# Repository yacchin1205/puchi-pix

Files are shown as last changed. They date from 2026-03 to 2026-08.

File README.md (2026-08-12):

# Puchi-Pix (ぷちぴく)

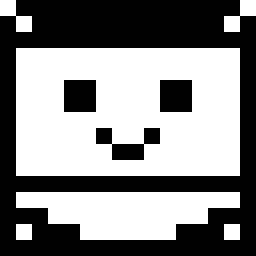
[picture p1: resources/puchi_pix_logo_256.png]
Puchi-Pix logo


A tiny pixel art display kit powered by STM32G030F6P, with a 96x64 OLED (SSD1331) or TFT display.

## Concept

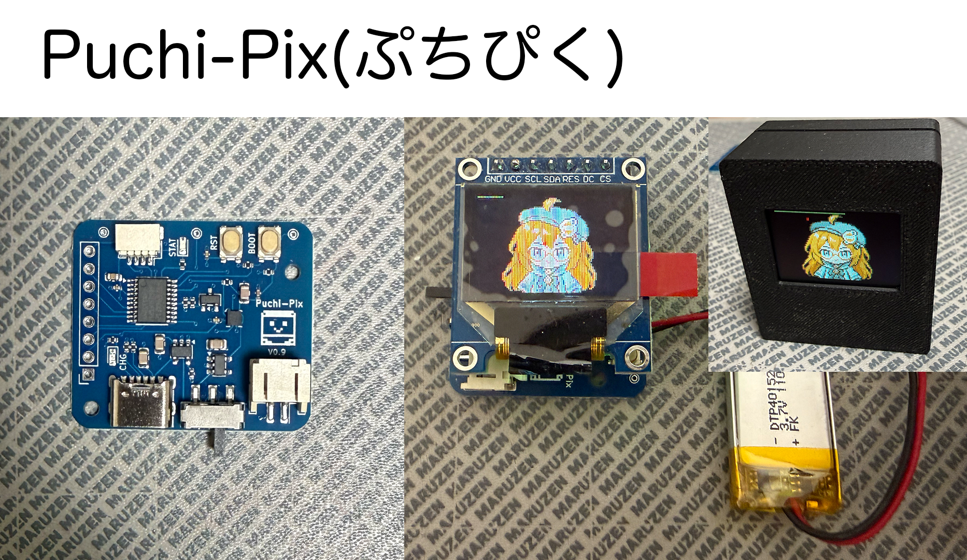
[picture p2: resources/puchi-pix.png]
Puchi-Pix overview


Puchi-Pix was born from a simple desire: to carry pixel art animations in your pocket.

It pairs an STM32G030F6P with a small OLED, targeting a keychain-sized form factor. Rather than a coin cell with its tedious battery swaps, the board integrates a LiPo charger on-board — unusual for something this small, but essential for a device meant to live in your pocket. Exposed GPIO and an onboard accelerometer also make it a capable dev board.

The STM32G030F6P has just 32KB of flash. Fitting animated pixel art into that space demands inter-frame delta compression, 4-bit palettes, and every byte counted. The kind of constraint that once made a project like this feel out of reach for a weekend hack.

Enter the age of coding agents. What used to take careful hand-optimization now becomes a conversation — iterate on compression schemes, generate frame data, and push against hardware limits at the speed of thought. The constraint doesn't go away, but it stops being a barrier and starts being a craft.

Puchi-Pix is a project built for this era — constrained hardware, creative ambition, and an AI coding agent to bridge the gap.

## STM32G030 BOOT0 pin issue

The factory default option bytes have `nBOOT_SEL=1`, which ignores the physical BOOT0 pin. A fresh (empty flash) chip boots into the bootloader automatically, but once firmware is written, the BOOT button has no effect.

Before the first firmware upload, set `nBOOT_SEL=0` via STM32CubeProgrammer CLI:

```bash
STM32_Programmer_CLI -c port=/dev/cu.usbserial-XXXXX br=115200 -ob nBOOT_SEL=0
```

Verify with:

```bash
STM32_Programmer_CLI -c port=/dev/cu.usbserial-XXXXX br=115200 -ob displ
```

`nBOOT_SEL : 0x0 (BOOT0 signal is defined by BOOT0 pin value (legacy mode))` means BOOT+RST will work.

## ESP32 upload fails despite BOOT+RST

On the ESP32 board, entering the bootloader with BOOT+RST sometimes doesn't take — the upload hangs at `Connecting...` for a while and then errors out with:

```
A fatal error occurred: Failed to connect to ESP32-C3: No serial data received.
```

BOOT (GPIO9) is a strapping pin sampled the moment reset is released, so what matters is the button order, not how long anything is held:

1. Press and **hold** BOOT
2. Press and release RST while still holding BOOT
3. Wait a beat, **then** release BOOT — releasing it before (or together with) RST boots the app normally instead
4. Give the USB port a second or two to re-enumerate, then start the upload

If it still fails, power-cycle the board completely and enter the bootloader
before plugging USB back in (on battery power) — this connects reliably:

1. Unplug USB
2. Slide switch OFF, then back ON
3. BOOT+RST (sequence above)
4. Plug USB back in, wait for the port to appear, then start the upload

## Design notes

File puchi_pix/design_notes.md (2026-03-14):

# AI支援によるKiCad PCB設計からJLCPCB発注まで — 体験記

## はじめに

STM32マイコンを使った小型デバイス「iconcard」（約30mm x 30mm x 10mm）のPCB設計を、AI（Claude Code）の支援を受けながら実施し、JLCPCBへのPCBA発注までを完走した。ユニバーサル基板のプロトタイプは動作済みで、KiCadで回路図も描いてあったが、PCB設計とPCBA発注は初めての経験だった。

本稿では、AIにどのような支援を求め、何がうまくいき、何に注意が必要だったかを記録する。

## デバイスの構成

| 部品 | 役割 |
|---|---|
| STM32G030F6Px (TSSOP-20) | MCU |
| SSD1331 OLED (96x64, SPI) | ディスプレイ |
| KXTJ3-1057 (LGA-12) | 加速度センサー |
| MCP73831 (SOT-23-5) | LiPo充電IC |
| AP2112K-3.3 (SOT-23-5) | 3.3V LDOレギュレータ |
| USB-C 6P | 充電用 |
| スライドスイッチ、タクトスイッチ×2 | 電源、BOOT、RST |

## 作業フロー全体像

```
回路図レビュー → 回路修正 → 部品選定 → フットプリント割り当て
→ PCBレイアウト → DRC/ERC → 製造ファイル生成 → JLCPCB発注
```

所要時間は2セッション（各数時間）。以下、各フェーズでAIに何を頼み、何が起きたかを記す。

---

## Phase 1: 回路図レビュー

### AIにできたこと

KiCadの回路図ファイル（`.kicad_sch`）はS式のテキストフォーマットなので、AIが直接読める。AIに回路図のレビューを依頼したところ、配線の座標を追跡して全接続を検証し、以下の問題を発見した。

- **MCP73831のVDD/STATピンが入れ替わっていた**（致命的）
- **LiPo電圧(4.2V)がSTM32の絶対最大定格(4.0V)を超える**（LDOの追加が必要）
- **電源スイッチがモメンタリだった**（スライドスイッチへの変更が必要）
- 未使用ピンのno_connectマーカー不足

### 実際のやりとり

> **自分:** 最初にユニバーサル基板で試作して、PCBを作ろうと回路図に起こしてみたんです。何か、回路図に抜けなどないか、レビューいただけますか
>
> **AI:** 回路図の全ワイヤ接続をトレースしました。コードのピンアサインと照合してレビューします。
>
> **1. MCP73831 の VDD と STAT が逆に配線されている可能性が高い**
>
> 現在の配線をトレースすると：
> - VDD (pin 4) → R8 (2K) → CHARGE_STATUS LED → VBUS
> - STAT (pin 1) → 未接続
>
> VDDはUSB電源入力ピンなのでVBUSに直結が必要です。現状ではR8+LEDで大きな電圧降下が発生し、充電ICが動作しません。
>
> **2. LiPo電圧がSTM32の定格を超える**
>
> VBAT（MCP73831出力 = 4.20V）がSW1を通じてSTM32 VDDに直結されています。STM32G030F6のVDD絶対最大定格は4.0V。満充電時の4.2Vで定格超過になります。

AIはKiCadの .kicad_sch ファイル（S式テキスト）を直接パースし、ワイヤ座標を追跡してピン接続を再構成する。ソースコード(.ino)のピンアサインとも照合した上で、配線ミスと定格超過を検出した。

### 教訓

AIは回路図のテキストデータを直接パースして接続を追えるので、セカンドオピニオンとして有効。ただし、回路図の「意図」は人間が持っているので、AIの指摘に対して自分で判断する必要はある。

---

## Phase 2: 回路修正

修正自体はKiCadの回路図エディタで自分で行い、保存後にAIに再確認を依頼するサイクルを回した。

- AP2112K-3.3 LDO追加（AIが推奨、データシートの接続を確認）
- スライドスイッチへの変更（DPDT → SPDTへ簡素化）
- ENピンのVIN接続、no_connectマーカー追加

### 実際のやりとり

> **自分:** 1.は回路図起こしの際のミスだったので、直しました。3.3V LDOレギュレータを追加（推奨） ってのは、どうやるのがおすすめ？
>
> **AI:** おすすめ: AP2112K-3.3。SOT-23-5で、MCP73831と同じパッケージです。低ドロップアウト（250mV @ 300mA）-- LiPoが3.5Vまで下がっても3.3V出力可能。低静止電流（55uA）-- スリープ時のバッテリー消費が小さい。

> **自分:** ありがとう。修正してみました。確認ください
>
> **AI:** EN → VIN 接続: OK。ワイヤを追跡した結果:
> ```
> U4 EN (132.08, 54.61) → (130.81, 54.61) → (130.81, 52.07) [junction] → U4 VIN
> ```
> ENピンがVINラインにジャンクション経由で正しく接続されています。
>
> スイッチ Pin 3 (C) の no_connect: 未追加。上側ポールのPin 3にはまだno_connectマーカーが付いていません。

KiCadの回路図は座標ベースのテキストデータなので、AIが修正前後の差分を読み取れる。「修正しました」→「確認ください」のサイクルを何度も回せるのが、この協業スタイルの利点。

---

## Phase 3: JLCPCB部品選定

### AIにできたこと

- JLCPCBの部品ページ（URL）を渡すと、スペック・在庫・価格を読み取って要件との適合を判断
- 部品種別ごとの選定ポイント（USB-Cのピン数、コネクタの極性、パッケージサイズ等）を助言
- Basic/Extended部品の違いとコストへの影響を説明
- EOL部品（廃番）の代替品探し

### 実際のやりとり

> **自分:** USB-Cコネクタ選定のポイントはなんだろうか
>
> **AI:** 回路図ではUSB-Cから使っているのは VBUS、GND、CC1/CC2（5.1Kプルダウン）だけ。D+/D-は使っていない。つまり電源供給専用なので、最小限のピンがあれば足ります。

> **自分:** https://jlcpcb.com/partdetail/CK-KMR221GLFS/C72443 こんなんでどうだろうか
>
> **AI:** C&K製で品質は良いですが、1個$0.51〜$0.62とかなり高いです。RST + BOOTで2個必要なので$1以上になります。RST/BOOTは開発時にしか使わないスイッチなので、安いもので十分とも言えます。どうしますか？

JLCPCBの部品ページのURLを貼ると、AIがページを取得してスペック・在庫・価格を読み取り、回路の要件との適合を判断してくれる。自分で部品を探し、AIに「これどう？」と聞くスタイルが効率的だった。

### 注意が必要だったこと

**JLCPCB部品の在庫は流動的。** 選定時に在庫があっても、発注時には0になっていることが複数回あった。タクトスイッチは3回変更することになった：

1. E-Switch TL3301AF160QG (6x6mm) → 在庫切れ
2. HX-3x6x2.5-X (3x6mm) → これも在庫切れ
3. Alps Alpine SKRPACE010 (4.2x3.2mm) → 在庫あり

部品変更のたびにフットプリント再生成が必要になるので、時間のロスが大きい。可能なら、在庫が潤沢な部品（数万個以上）を選ぶか、Basic partを優先するのが良い。

---

## Phase 4: フットプリント割り当て

### easyeda2kicad — 重要ツール

JLCPCBの部品にはEasyEDA形式のフットプリントが用意されているが、KiCadでは直接使えない。`easyeda2kicad` というPythonツールで変換できる：

```bash
pip install easyeda2kicad
easyeda2kicad --full --lcsc_id C139797 --output ./custom_footprints/SKRPACE010
```

LCSC番号を指定するだけで、シンボル・フットプリント・3Dモデルが生成される。EasyEDAのアカウント登録は不要。

### パッド名の不一致問題

生成されたフットプリントのパッド名が、KiCadの回路図シンボルのピン名と一致しないことがある。これは手動で修正が必要：

- **タクトスイッチ（4パッド → 2ピン）:** 内部で繋がっているパッド同士を同じピン番号にリネーム。**必ずデータシートで内部接続を確認すること。**
- **USB-C:** シールドパッド「7」→「S1」にリネーム

### 実際のやりとり

> **自分:** EasyEDAという画面が開いたが... ダウンロードできるのだろうか。Registerする必要がある？
>
> **AI:** もっと簡単な方法があります。easyeda2kicad コマンドラインツール -- アカウント不要で、JLCPCB部品番号からKiCadフットプリントを直接生成できます。
> ```
> pip install easyeda2kicad
> easyeda2kicad --lcsc_id C49023767 --output ./custom_footprints/MST-12D18G4
> ```

> **自分:** SW, USB-Cをフットプリント割り当てしたが、SWもピン表記が違うよね。きっと。
>
> **AI:** パッド名を確認しました。タクトスイッチ -- KiCadの SW_Push シンボルはピン2つ（1と2）しかありません。フットプリントは4パッドです。左の2パッド → 両方とも "1" に、右の2パッド → 両方とも "2" に。

AIはフットプリントファイル（.kicad_mod）も直接読めるので、パッド名の不一致を検出できる。ただし、どのパッド同士が内部接続されているかはデータシートの確認が必須。実際、自分がデータシートを見ずにリネームしてしまい、やり直すことになった。

---

## Phase 5: PCBレイアウト

PCBレイアウト自体はKiCadのPCBエディタで手動で行った。AIに聞いて役立った知識：

- **GND戦略:** B.Cu（裏面）をGNDベタにして、デカップリングコンデンサのGNDパッドからビアで落とす
- **ビア配置:** GNDパッドの近くに配置するほどインピーダンスが下がる
- **シルクスクリーン:** F.SilkSは基板に印刷される、F.Fabは印刷されない
- **ネジ穴:** `MountingHole` フットプリントを使用、30mm基板ならM2サイズ

### 実際のやりとり

> **自分:** 配線で、GNDはどうするのが良いかな
>
> **AI:** 基本方針は裏面（B.Cu）をGNDベタプレーンにすることです。GNDの配線は引かない -- 各部品のGNDパッドにビアだけ打ちます。

> **自分:** GNDピアと端子の間は狭い方が良い？
>
> **AI:** はい、狭い方が良いです。特に重要なのはデカップリングコンデンサのGNDパッドです。ここの配線が長いと、コンデンサの効果が薄れます。理想はコンデンサのGNDパッドから 0.3〜0.5mm の距離にビアです。

PCBレイアウトのGUI操作はAIにはできないが、「何をどう配置すべきか」「なぜそうすべきか」の知識は正確に提供してくれる。手を動かすのは自分、判断の根拠はAIに聞く、という分担。

---

## Phase 6: DRC/ERC

KiCadのDRC/ERCレポート（`.rpt`ファイル）をAIに読ませると、各エラーの意味と対処法を日本語で解説してくれる。

主な問題と対処：

| エラー | 原因 | 対処 |
|---|---|---|
| annular_width | スイッチ固定穴のパッド径 < ドリル径 | PTH → NPTHに変更 |
| power_pin_not_driven | 電源入力ピンの駆動元がない | PWR_FLAGシンボルを追加 |
| unconnected_items | 配線未完了 | 配線を完了 |
| silk_edge_clearance | シルクが基板端からはみ出し | cosmetic、無視可 |

### 実際のやりとり

> **自分:** 自分で直せそうな奴は直したのだが、20260301 ってreportファイルを保存した
>
> **AI:** *(レポートファイルを読んで)* スライドスイッチ(Power)の固定穴 x2 -- アニュラー幅が-0.004mmになっている。穴に対してパッドが小さすぎます。

> **自分:** 電気的に不要 と思っていいですよね。
>
> **AI:** はい、その通りです。Power スライドスイッチの2つの取り付け穴は機械的な固定専用で、電気的には不要です。PTH → NPTHに変更すれば、annular_widthエラーとpadstack警告の計4件が一度に解消します。

KiCadのDRC/ERCが出力する .rpt ファイル（日本語）をそのままAIに渡すと、各エラーの意味を噛み砕いて説明し、具体的な修正手順を示してくれる。

**回路図↔PCBの整合性チェック** はPCBエディタのF8（回路図から基板を更新）で「変更なし」が出れば一致している。

---

## Phase 7: 製造ファイル生成

### Fabrication Toolkit（KiCadプラグイン）

KiCadのPlugin & Content ManagerからインストールできるFabrication Toolkitが便利。ワンクリックでJLCPCB向けのGerber、BOM、CPLファイルを生成する。

### 落とし穴

1. **LCSCフィールドが空になる:** 回路図でLCSCフィールドを追加した後、PCBエディタでF8して同期しないとBOMに反映されない
2. **DNPとExclude from BOMは別:** 回路図上の×マーク（DNP）だけではBOMから除外されない。「Exclude from BOM」チェックが別途必要
3. **production/backups/ が生成される:** .gitignoreに追加しておくのが良い

### 実際のやりとり

> **自分:** OK, production ディレクトリができた。どうだろうか
>
> **AI:** *(BOM CSVを読んで)* ファイル生成は成功しています。2点修正が必要です。LCSC Part # が全て空です。DISPLAY（J2）が BOM に含まれています。

> **自分:** LCSCの項目に、列チェックが入っていなかったので、入れ直してみました
>
> **AI:** *(再度読んで)* まだ空ですね。おそらく回路図の変更がPCBに反映されていないのが原因です。Fabrication Toolkit はPCBファイルから BOM を生成するので、回路図で追加した LCSC フィールドをPCBに同期する必要があります。PCBエディタで F8 → 適用 → 再度 Generate してください。

AIが生成されたCSVファイルを直接読んでチェックしてくれるので、「生成→確認→修正→再生成」のサイクルを素早く回せた。LCSCフィールドがPCBに同期されないというKiCad特有の落とし穴も、AIの指摘で解決できた。

---

## Phase 8: JLCPCB発注

### 発注の流れ

1. jlcpcb.com で Gerber ZIP をアップロード → PCB仕様を選択
2. PCBAを有効化 → BOM CSV と CPL CSV をアップロード
3. 部品マッチング確認 → コンポーネント配置プレビュー → 発注

### 「Confirm Parts Placement」はYesにすべき

JLCPCBのエンジニアが部品配置をレビューしてくれる。追加費用なし。今回、**これがSTM32のLCSC番号誤りを検出してくれた。**

### LCSC番号の取り違え — 最大の失敗

BOMに記載したU1のLCSC番号 C526973 は、実はSTM32G030F6Pxではなく**10pF 0402コンデンサ**だった。JLCPCBのエンジニアが「パッケージが合わない」と連絡してきて発覚。

**対策:** 発注前に、全LCSC番号をJLCPCBの部品ページで照合すべき。AIに頼んで全件検証したところ、この1件以外は全て正しかった。番号の出典が不確かなものは特に注意。

### 実際のやりとり

> **自分:** *(JLCPCBのエンジニア Doris からのメールを貼り付けて)*
> "seems the packages of the parts (U1) cannot match the corresponding pads on the PCB board, so we are unable to assemble them."
>
> **AI:** 原因がわかりました！ C526973 は STM32G030F6Px ではなく、0402 コンデンサ (10pF) です。LCSC 番号が間違っています。正しい番号は C724040 です。

> **自分:** ありがとう。念の為、BOMをチェックしてもらっていいですか。他に取り違えがあるのなら知っておきたい
>
> **AI:** *(全19部品のLCSC番号をJLCPCBのWebページで1件ずつ照合して)* 全19部品の検証が完了しました。問題は U1 の1件のみです。

> **自分:** ありがとう、迅速な対応への感謝をメッセージに入れたい。
>
> **AI:** "Hi Doris, thank you for catching this so quickly! Please go with option A. The correct part for U1 should be LCSC# C724040 (STM32G030F6P6, TSSOP-20). Thank you for your help!"

LCSC番号の問題が発覚した際、AIがWebページを取得して番号の実体を調べ、正しい番号を検索し、さらにBOM全件を1つずつ照合してくれた。英語の返信文も起草してくれる。Confirm Parts Placementを有効にしていたおかげで、製造前にこの問題をキャッチできた。

### コスト構造（5枚PCBA時）

| 項目 | 金額 |
|---|---|
| 固定費（設定・ステンシル・フィーダー等） | ~¥10,275 |
| 変動費（1枚あたり） | ~¥489 |
| **5枚合計** | **~¥12,247** |

固定費が支配的なので、枚数を増やすほど単価は下がる。¥1,000/枚を切るには約20枚必要。

---

## AIの活用まとめ

### 特に有効だった場面

| 場面 | AIの役割 |
|---|---|
| 回路図レビュー | S式テキストを直接パースして全接続を検証 |
| 部品選定 | JLCPCBの部品ページを読み取り、スペック適合を判断 |
| DRC/ERCレポート解読 | 日本語で各エラーの意味と対処法を解説 |
| BOM全件検証 | 全LCSC番号をWebで照合、取り違えを検出 |
| KiCad操作ガイド | フットプリントライブラリ追加、Fabrication Toolkit等の手順説明 |
| .gitignore作成 | KiCad特有の一時ファイルを適切に除外 |

### AIにできなかったこと

- **KiCad GUIの直接操作:** フットプリント割り当て、パッドリネーム、PCBレイアウト、配線は全て手動
- **部品の実物確認:** データシートの物理寸法の最終判断は人間が行う必要がある
- **JLCPCBの在庫リアルタイム確認:** Web上の在庫とPCBA在庫は別管理の場合があり、正確な判断は発注画面でしかできない

### 使用したツール

| ツール | 用途 |
|---|---|
| KiCad 9 | 回路図・PCB設計 |
| easyeda2kicad (pip) | JLCPCB部品のKiCadフットプリント変換 |
| Fabrication Toolkit (KiCadプラグイン) | JLCPCB向け製造ファイル一括生成 |
| Claude Code | 回路図レビュー、部品選定支援、DRC解読、BOM検証、手順ガイド |

---

## 次にやるなら気をつけること

1. **LCSC番号は必ず照合する。** 手入力ミスは起きる。発注前に全件検証を。
2. **在庫の多い部品を選ぶ。** 数百個レベルの在庫は発注時に0になりうる。Basic partを優先。
3. **Confirm Parts Placementは必ずYes。** 無料で、致命的ミスのセーフティネットになる。
4. **easyeda2kicadのパッド名は信用しない。** データシートと突き合わせてリネームが必要。
5. **KiCadのLCSCフィールド追加後はF8で同期。** 忘れるとBOMに反映されない。

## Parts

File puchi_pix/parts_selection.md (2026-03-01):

# iconcard 部品選定メモ

基板サイズ: 約30mm x 30mm x 10mm
実装: JLCPCB PCBA (SMD実装)

## IC（フットプリント割り当て済み）

| Ref | 部品 | パッケージ | JLCPCB# | 備考 |
|-----|---|---|---|---|
| U1 | STM32G030F6Px | TSSOP-20 | C724040 | MCU |
| U2 | KXTJ3-1057 | LGA-12 (2x2mm) | C442603 | 加速度計 |
| U3 | MCP73831-2-OT | SOT-23-5 | C424093 | LiPo充電IC |
| U4 | AP2112K-3.3 | SOT-23-5 | C51118 | 3.3V LDOレギュレータ |

## コネクタ・スイッチ（JLCPCB部品選定済み）

| Ref | 部品 | JLCPCB# | 型式 | 備考 |
|-----|---|---|---|---|
| J4 | USB-Cレセプタクル 6P | C456012 | SHOU HAN TYPE-C 6P | 充電専用。シンボル: USB_C_Receptacle_PowerOnly_6P |
| Power | スライドスイッチ SPDT | C49023767 | MST-12D18G4 | 電源ON/OFF。シンボルをSPDTに変更済み |
| J1 | SHコネクタ 4P (1.0mm) | C7527619 | XDWF-0910-04P | デバッグ/UART用。常設 |

## 未選定の部品

### コネクタ

| Ref | 種類 | 仕様 | メモ |
|-----|---|---|---|
| J2 | ピンソケット 2.54mm 7pin | OLED接続用 | **PCBA除外・手はんだ**。フットプリントのみ基板に配置 |
| J3 | JST-PH 2pin (2.0mm) | C968533 | BOOMELE PH-2P SMD横型 | LiPoバッテリー用。**極性注意** |

### スイッチ

| Ref | 種類 | JLCPCB# | 型式 | メモ |
|-----|---|---|---|---|
| RST1 | タクトスイッチ | C139797 | ALPS ALPINE SKRPACE010 | 4.2x3.2x2.5mm SMD |
| BOOT1 | タクトスイッチ | C139797 | ALPS ALPINE SKRPACE010 | 同上 |

### 抵抗（全て UNI-ROYAL 0402 ±1% Basic part）

| Ref | 値 | JLCPCB# | 型式 | 用途 |
|-----|-----|---|---|---|
| R1 | 10K | C25744 | 0402WGF1002TCE | BOOT0プルダウン |
| R2 | 2K | C4109 | 0402WGF2001TCE | LED電流制限 |
| R3 | 2.2K | C25879 | 0402WGF2201TCE | I2Cプルアップ |
| R4 | 2.2K | C25879 | 0402WGF2201TCE | I2Cプルアップ |
| R5 | 5.1K | C25905 | 0402WGF5101TCE | USB-C CC1プルダウン |
| R6 | 5.1K | C25905 | 0402WGF5101TCE | USB-C CC2プルダウン |
| R7 | 4.99K | C25903 | 0402WGF4991TCE | MCP73831 PROG (充電≒200mA) |
| R8 | 2K | C4109 | 0402WGF2001TCE | LED電流制限 |

### コンデンサ

| Ref | 値 | サイズ | JLCPCB# | 型式 | 分類 | 用途 |
|-----|-----|---|---|---|---|---|
| C1 | 0.1uF | 0402 | C309458 | YAGEO CC0402KRX7R6BB104 (10V X7R) | Extended | デカップリング |
| C2 | 4.7uF | 0603 | C19666 | Samsung CL10A475KO8NNNC (16V X5R) | Basic | MCP73831 VBAT側 |
| C3 | 0.1uF | 0402 | C309458 | (同上) | Extended | デカップリング |
| C4 | 0.1uF | 0402 | C309458 | (同上) | Extended | デカップリング |
| C5 | 10uF | 0805 | C380332 | CCTC TCC0805X5R106K160FT (16V X5R) | Extended | デカップリング |
| C6 | 10uF | 0805 | C380332 | (同上) | Extended | MCP73831 VDD側 |
| C7 | 0.1uF | 0402 | C309458 | (同上) | Extended | KXTJ3デカップリング |
| C8 | 10uF | 0805 | C380332 | (同上) | Extended | AP2112K入力 |
| C9 | 10uF | 0805 | C380332 | (同上) | Extended | AP2112K出力 |

### LED（0603）

| Ref | 色 | JLCPCB# | 型式 | Vf | メモ |
|-----|-----|---|---|-----|---|
| CHARGE_STATUS | 赤 | C2286 | KT-0603R (Hubei KENTO) | 2.4V | Basic part。R8=2K → 約0.45mA |
| STM32_STATUS | 緑 | C12624 | KT-0603G (Hubei KENTO) | 3.1V | Extended。R2=2K → 約0.1mA（暗め。必要ならR値下げ検討） |

## フットプリント割り当て

全部品のフットプリント割り当て完了。カスタムフットプリントは `custom_footprints/` に格納:
- `MST-12D18G4.pretty` — スライドスイッチ (C49023767)
- `SKRPACE010.pretty` — タクトスイッチ (C139797) ※パッド名を上段=1, 下段=2にリネーム済み
- `TYPE-C-6P.pretty` — USB-C 6P (C456012) ※シールドパッド名を7→S1にリネーム済み

## 回路図修正履歴

- [x] MCP73831 VDD/STAT ピンスワップ修正
- [x] AP2112K-3.3 LDO追加（U4）
- [x] パワースイッチをスライドスイッチに変更（DPDT → SPDT）
- [x] AP2112K ENピンをVINに接続
- [x] スイッチ未使用ピンにno_connectマーカー追加
- [x] USB-CシンボルをUSB_C_Receptacle_PowerOnly_6Pに変更（J4）

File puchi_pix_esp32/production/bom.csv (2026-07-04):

Designator | Footprint | Quantity | Value | LCSC Part #
C1 | 0402 | 1 | 1u | C52923
C2 | 0402 | 1 | 0.1u | C309458
C3 | 0805 | 1 | 10u | C380332
C4, C5, C6, C7 | 0805 | 4 | 10uF | C380332
C8, C9 | 0402 | 2 | 0.1uF | C309458
CHG1 | 0603 | 1 | LED | C2286
D1 | 0603 | 1 | LED | C12624
J1 | USB_C_Receptacle_HRO_TYPE-C-31-M-12 | 1 | USB_C_Receptacle_USB2.0_16P | C165948
J3 | JST_PH_S2B-PH-SM4-TB_1x02-1MP_P2.00mm_Horizontal | 1 | JST-PH | C968533
POWER1 | SW-SMD_MST-12D18G4-SPDT-SLIDE-SWITCH | 1 | SW_SPDT | C49023767
R1, R16, R2, R4, R5 | 0402 | 5 | 10k | C25744
R10 | 0402 | 1 | 4K99 | C25903
R11 | 0402 | 1 | 2K | C4109
R12, R13 | 0402 | 2 | 2.2K | C25879
R14, R15 | 0402 | 2 | 100 | C25076
R3 | 0402 | 1 | 4.7k | C25900
R6, R7 | 0402 | 2 | 22 | C25092
R8, R9 | 0402 | 2 | 5K1 | C25905
SW1 | KEY-SMD_4P-L4.2-W3.2-P2.20-LS4.6 | 1 | BOOT | C139797
SW2 | KEY-SMD_4P-L4.2-W3.2-P2.20-LS4.6 | 1 | RST | C139797
U1 | ESP32-C3-MINI-1 | 1 | ESP32-C3-MINI-1 | C2838502
U2 | SOT-23-5 | 1 | MCP73831-2-OT | C424093
U3 | Kionix_LGA-12_2x2mm_P0.5mm_LayoutBorder2x4y | 1 | KXTJ3-1057 | C442603
U4 | SOT-23-5 | 1 | AP2112K-3.3 | C51118

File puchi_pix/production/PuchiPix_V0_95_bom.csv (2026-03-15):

Designator | Footprint | Quantity | Value | LCSC Part #
BOOT1, RST1 | KEY-SMD_4P-L4.2-W3.2-P2.20-LS4.6 | 2 | SW_Push | C139797
C1, C3, C4, C7 | 0402 | 4 | 0.1uF | C309458
C2 | 0603 | 1 | 4.7uF | C19666
C5, C6, C8, C9 | 0805 | 4 | 10uF | C380332
CHG1 | 0603 | 1 | LED | C2286
J1 | JST_SH_SM04B-SRSS-TB_1x04-1MP_P1.00mm_Horizontal | 1 | JST-SH | C7527619
J3 | JST_PH_S2B-PH-SM4-TB_1x02-1MP_P2.00mm_Horizontal | 1 | JST-PH | C968533
J4 | TYPE-C-SMD_TYPE-C-6P_1 | 1 | USB_C_Receptacle_PowerOnly_6P | C456012
POWER1 | SW-SMD_MST-12D18G4-SPDT-SLIDE-SWITCH | 1 | SW_SPDT | C49023767
Q1 | SOT-23 | 1 | 2N7002 | C8545
R1 | 0402 | 1 | 10K | C25744
R10 | 0402 | 1 | 100K | C25741
R2 | 0402 | 1 | 4.7K | C25900
R3, R4 | 0402 | 2 | 2.2K | C25879
R5, R6 | 0402 | 2 | 5K1 | C25905
R7 | 0402 | 1 | 4K99 | C25903
R8 | 0402 | 1 | 2K | C4109
R9 | 0402 | 1 | 100 | C25076
STAT1 | 0603 | 1 | LED | C12624
TP1 | TestPoint_THTPad_D1.0mm_Drill0.5mm | 1 | SWDIO
TP2 | TestPoint_THTPad_D1.0mm_Drill0.5mm | 1 | SWCLK
TP3 | TestPoint_THTPad_D1.0mm_Drill0.5mm | 1 | GND
U1 | TSSOP-20_4.4x6.5mm_P0.65mm | 1 | STM32G030F6Px | C724040
U2 | Kionix_LGA-12_2x2mm_P0.5mm_LayoutBorder2x4y | 1 | KXTJ3-1057 | C442603
U3 | SOT-23-5 | 1 | MCP73831-2-OT | C424093
U4 | SOT-23-5 | 1 | AP2112K-3.3 | C51118

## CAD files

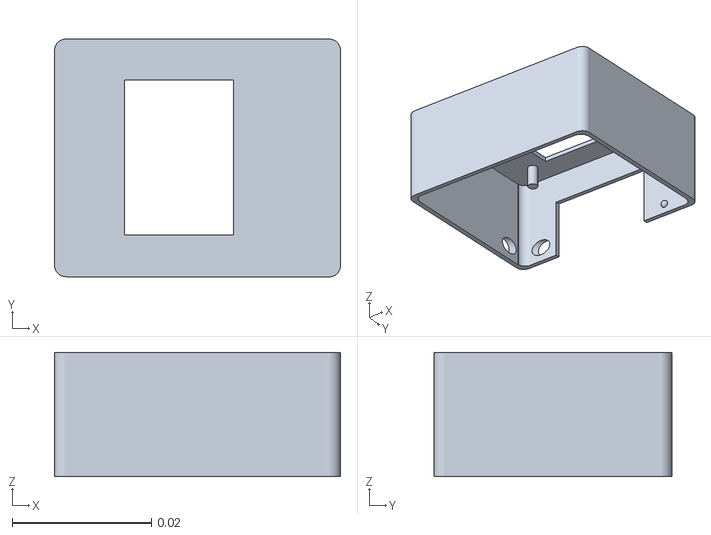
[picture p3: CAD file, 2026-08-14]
box/box-u.stl
0.041 x 0.0341 x 0.0178

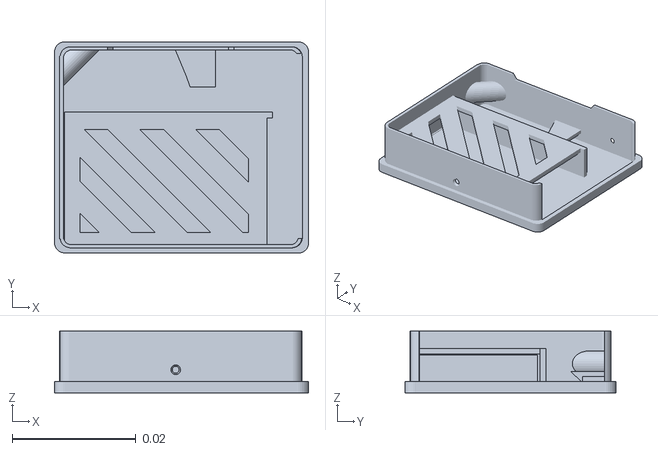
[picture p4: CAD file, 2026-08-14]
box/box-l.stl
0.041 x 0.0341 x 0.00996

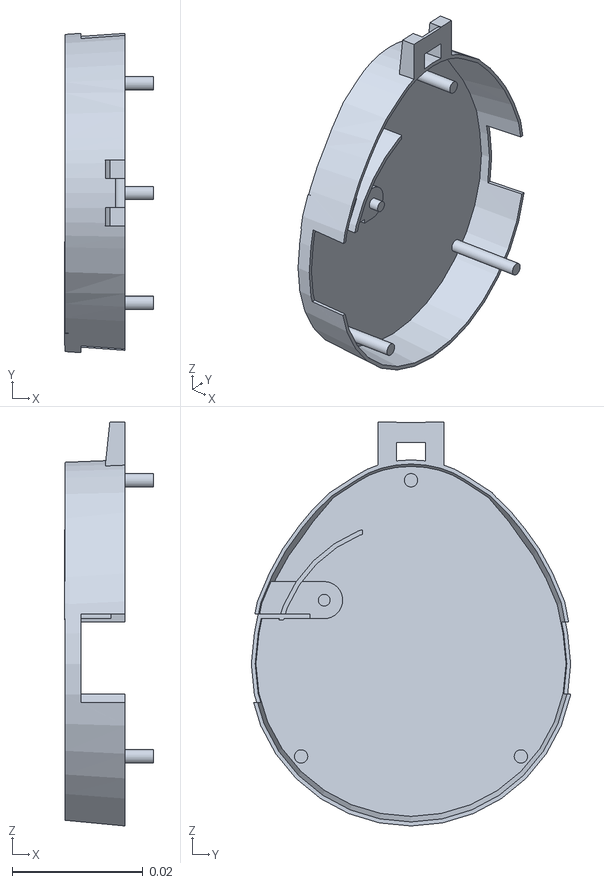
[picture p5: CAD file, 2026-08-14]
box/box-esp32-c.stl
0.0137 x 0.0489 x 0.0618

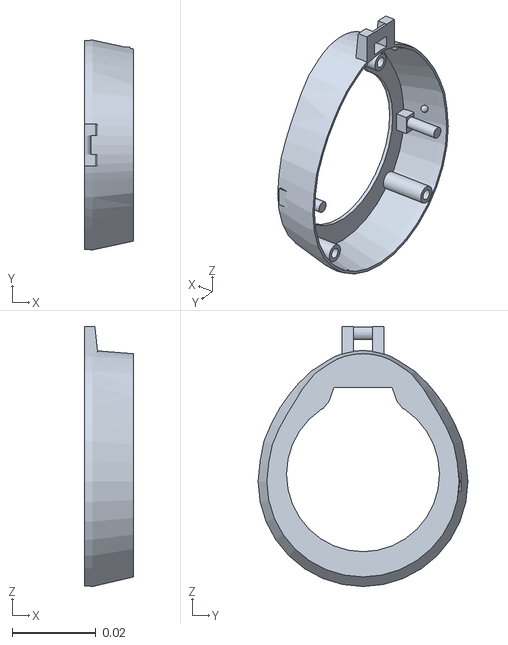
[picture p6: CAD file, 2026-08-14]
box/box-esp32-a.stl
0.0117 x 0.0501 x 0.062

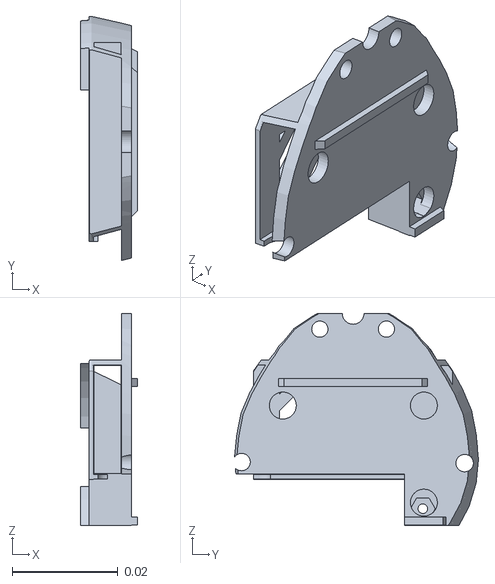
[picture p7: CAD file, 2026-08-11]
box/box-esp32-b.stl
0.0108 x 0.0462 x 0.0402

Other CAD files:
box/box-esp32.blend
box/box-support.blend
box/box.blend

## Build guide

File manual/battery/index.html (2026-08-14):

Puchi-Pix 取扱説明

# 準備: バッテリーの接続

Puchi-Pix は電池なしの状態でお渡ししています。はじめに、以下の手順でバッテリーを取り付けてください。

対応バッテリー: DTP502035(3.7V / 300mAh、コネクタ付きリチウムポリマー電池)

このバッテリーのみサポートしています。

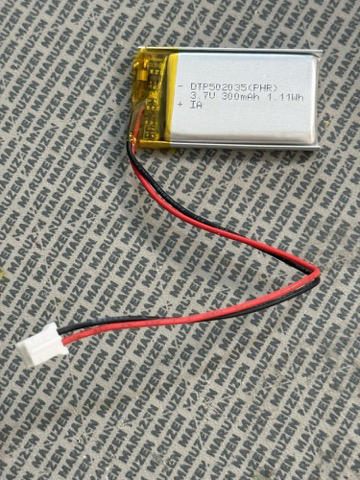
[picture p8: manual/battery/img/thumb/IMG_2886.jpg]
DTP502035 バッテリー


## 丸型 (ESP32版)

### 1裏蓋を外す

裏蓋と表枠の継ぎ目に爪を引っ掛けて、徐々に開けて外します。

⚠️ 裏蓋を接続しているピンは弱いため、一気にこじ開けるとピンが折れることがあります。少しずつ開けてください。

裏蓋を持ち上げて外す

### 2基板を取り出す

基板の裏側にはバッテリーケースが取り付けられています。バッテリーを入れられるよう、基板ごとケースの表枠から取り外します。

基板を表枠から取り外す

### 3バッテリーを接続する

バッテリーのコネクタを、基板のコネクタに奥まで差し込みます。

バッテリーのコネクタを基板に差し込む

### 4バッテリーを収納する

基板裏のバッテリーケースに、バッテリーを横からスライドさせて入れます。

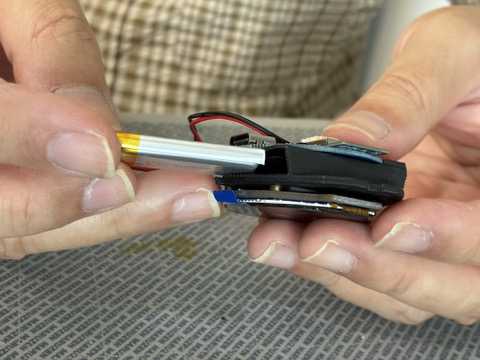
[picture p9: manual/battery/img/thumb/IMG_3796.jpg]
バッテリーをバッテリーケースにスライドして入れる


### 5基板をケースに戻す

ケースの表枠にあるピンに基板を合わせるようにして収めます。リード線を挟み込まないように注意してください。

基板をケースに戻す

### 6裏蓋を閉じる

裏蓋のピンを合わせて閉じます。

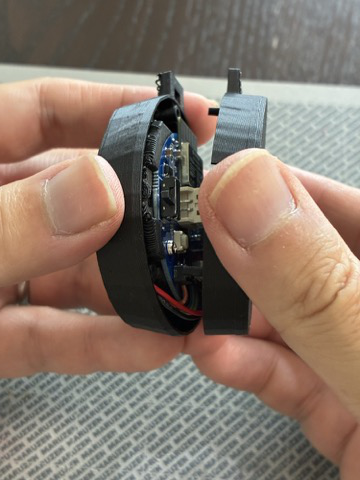
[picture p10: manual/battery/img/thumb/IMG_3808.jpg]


### 7動作確認

側面のスイッチをONにして、画面が表示されれば完了です。

画面が表示された完成状態

## 角型 (STM32版)

### 1裏蓋を外す

裏蓋の継ぎ目に爪をかけ、外します。

裏蓋を持ち上げて外す

### 2基板を取り出す

基板をケースから取り出します。

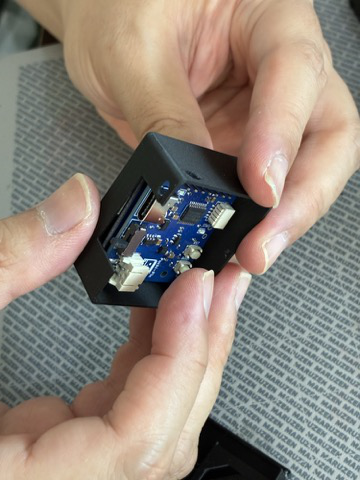
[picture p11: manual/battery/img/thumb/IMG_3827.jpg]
基板をケースから取り出す


### 3表枠とディスプレイを外す

表枠とディスプレイモジュールを分離します。

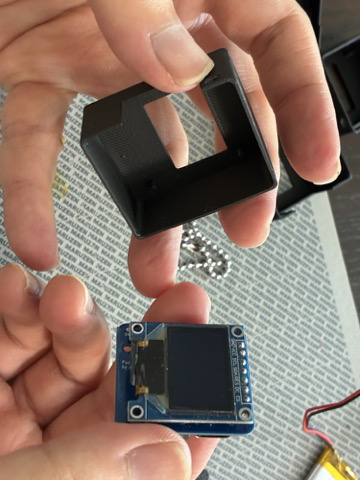
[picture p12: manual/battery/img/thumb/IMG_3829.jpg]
表枠とディスプレイモジュールを分離する


### 4バッテリーを接続する

バッテリーのコネクタを、基板のコネクタに奥まで差し込みます。

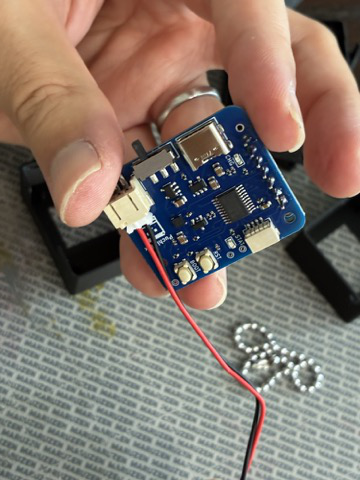
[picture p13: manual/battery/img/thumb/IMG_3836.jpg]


### 5バッテリーを電池ケージに収める

裏蓋の電池ケージにバッテリーを納め、リード線は押さえピンに引っ掛けます。

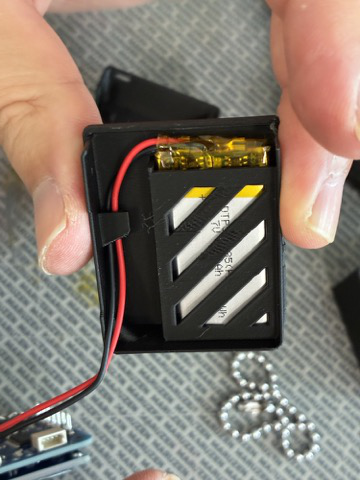
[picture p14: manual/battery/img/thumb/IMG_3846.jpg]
バッテリーを電池ケージに収める


### 6基板をケースに戻す

USB-C・スイッチが側面の窓に合う向きで収めます。

基板をケースに戻す

### 7ディスプレイと表枠を戻す

ディスプレイモジュールを表枠にはめ、ケースの前面に取り付けます。

ディスプレイと表枠を戻す

### 8裏蓋を閉じる

裏蓋を閉じます。裏蓋は、写真のようにボールチェーン穴がない側面を先にはめてから、押し込むとやりやすいです。

裏蓋を閉じる

### 9動作確認

側面のスイッチをONにして、画面が表示されれば完了です。

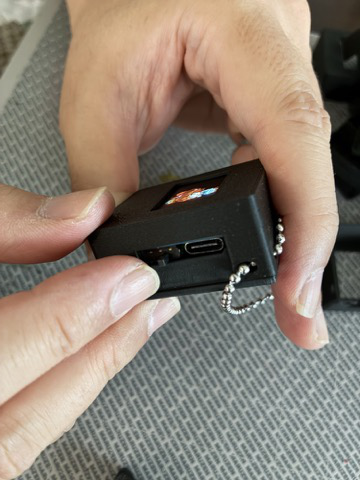
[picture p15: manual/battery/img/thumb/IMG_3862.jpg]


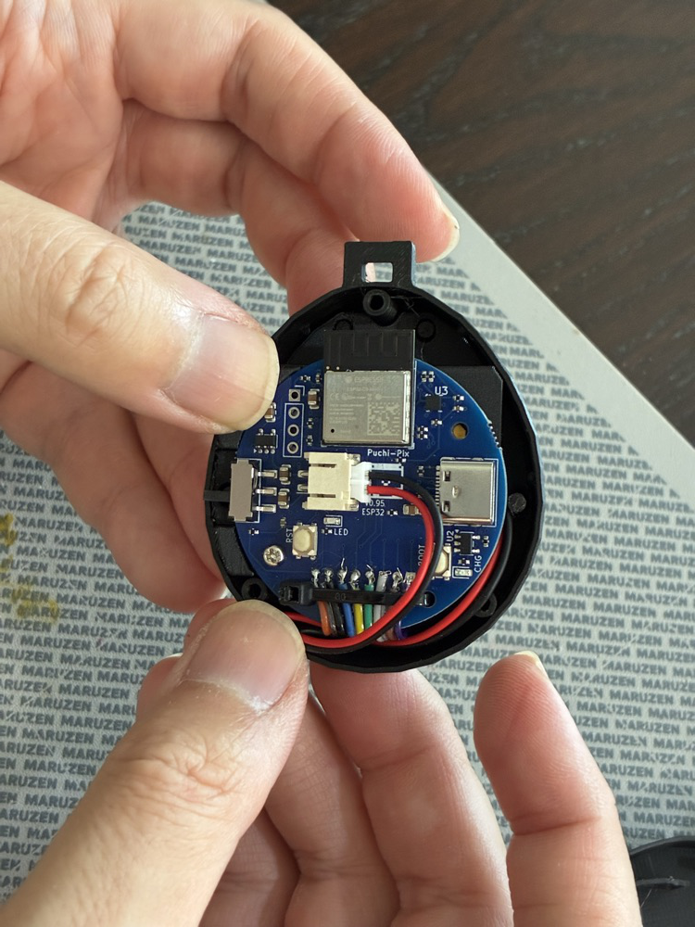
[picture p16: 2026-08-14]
manual/battery/img/IMG_3804.jpg

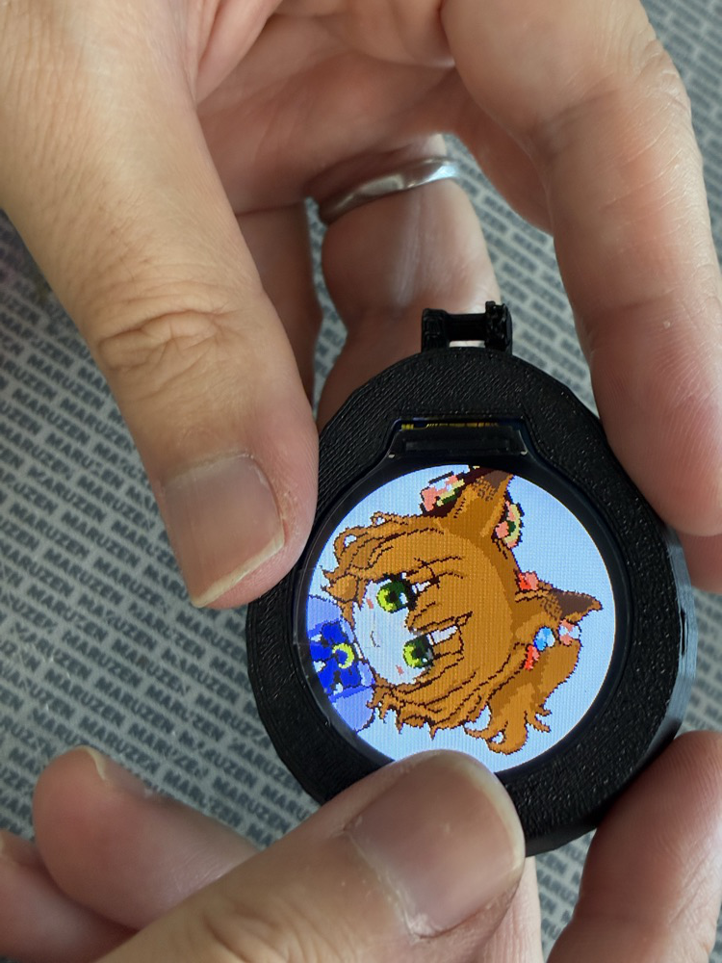
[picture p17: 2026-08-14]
manual/battery/img/IMG_3812.jpg

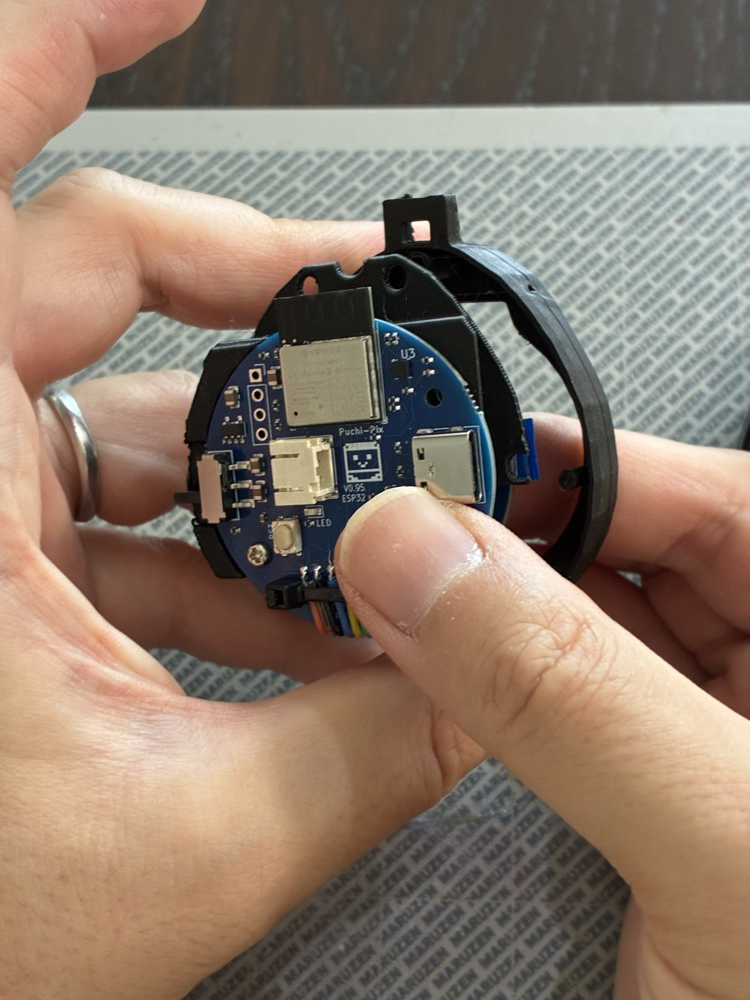
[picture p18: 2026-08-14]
manual/battery/img/IMG_3787.jpg

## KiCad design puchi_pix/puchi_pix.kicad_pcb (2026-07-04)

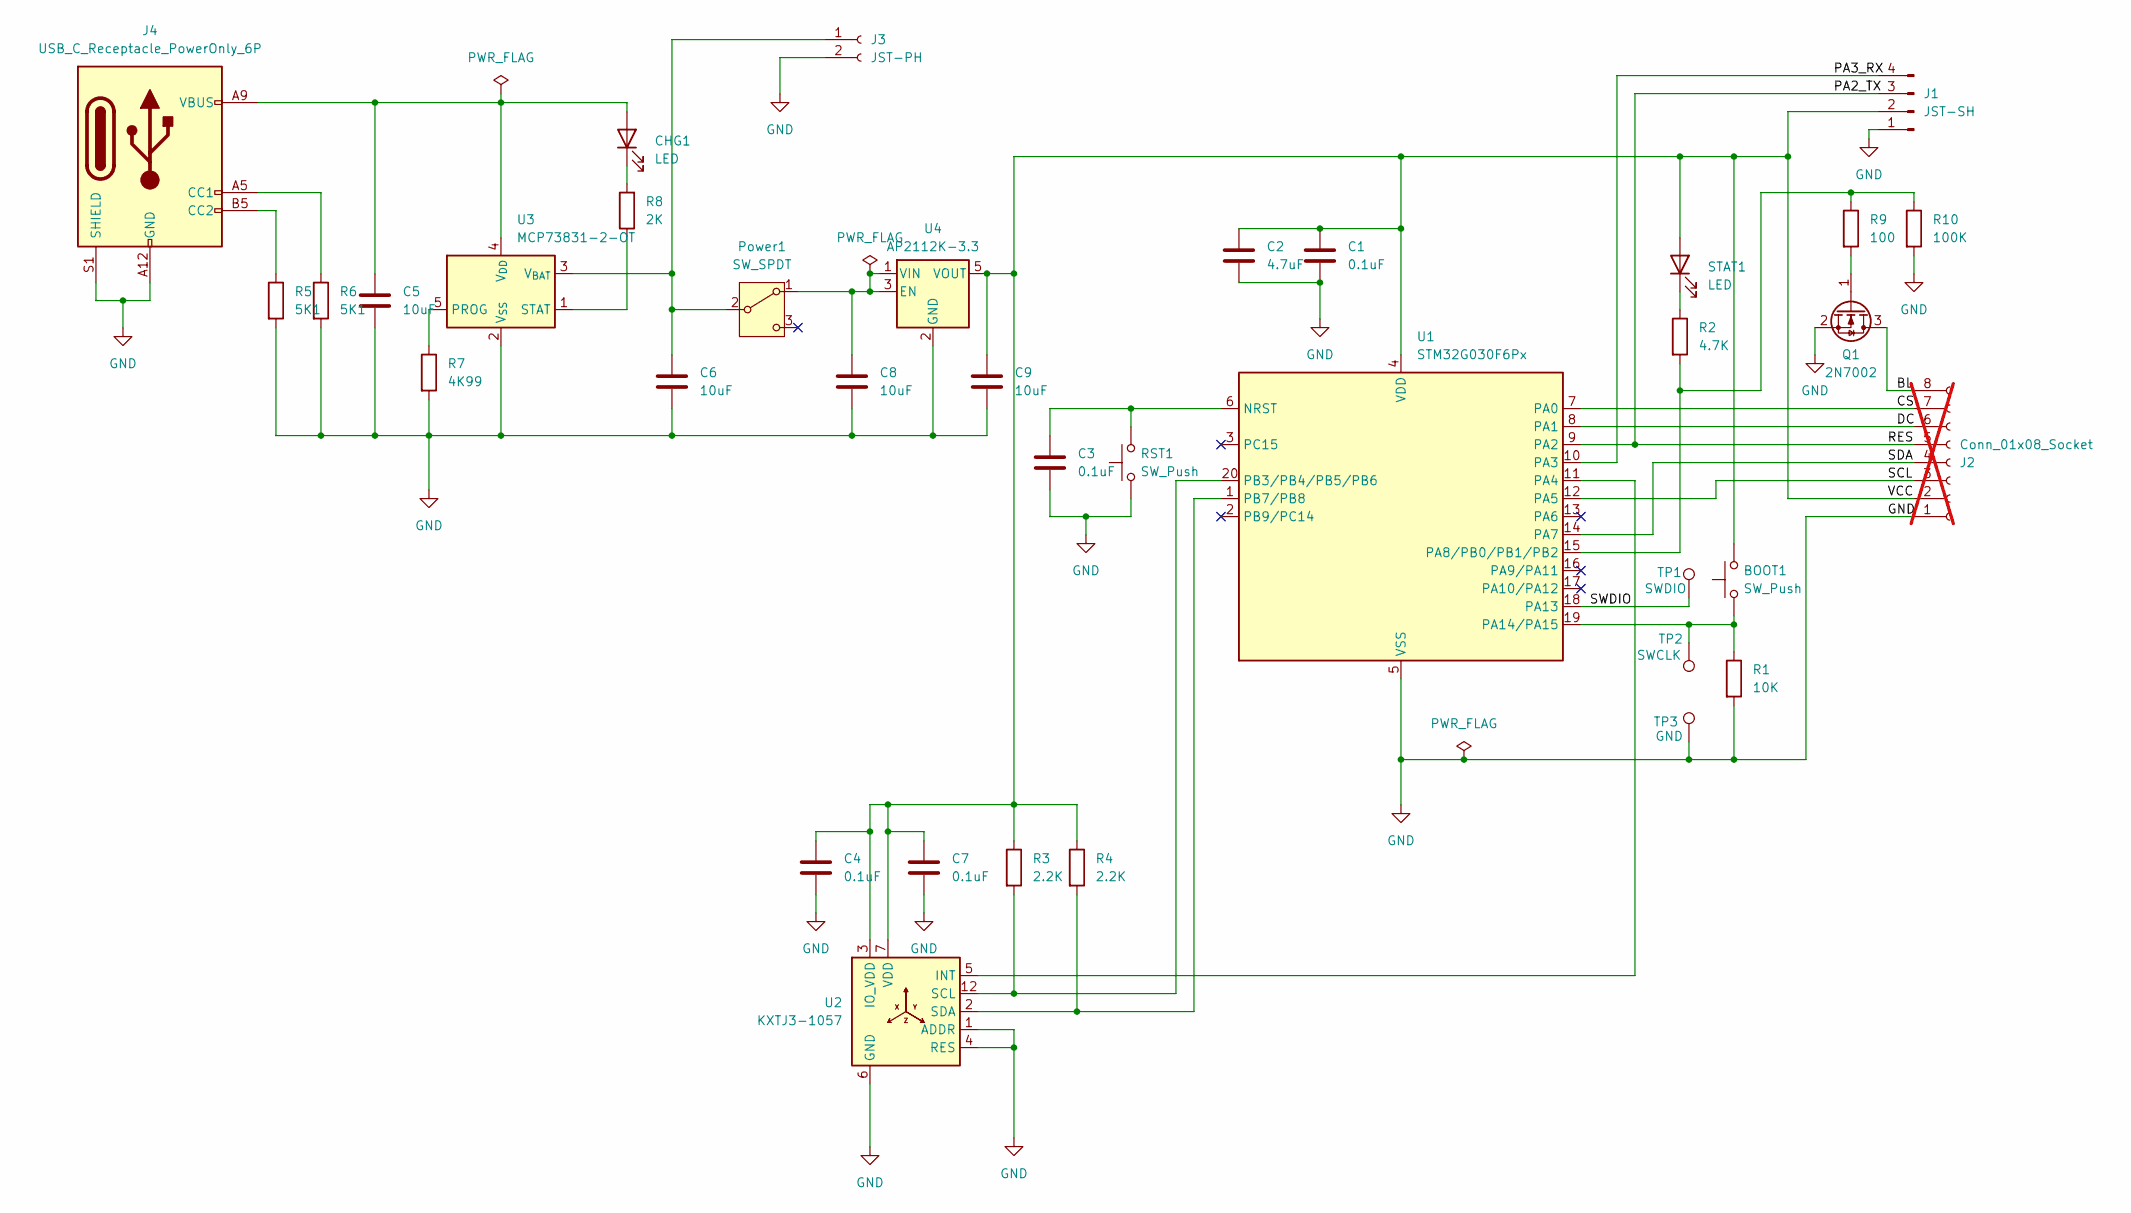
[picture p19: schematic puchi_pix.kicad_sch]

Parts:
BOOT1: SW_Push; KEY-SMD_4P-L4.2-W3.2-P2.20-LS4.6; LCSC C139797
C1, C3, C4, C7: 0.1uF; C_0402_1005Metric; LCSC C309458
C2: 4.7uF; C_0603_1608Metric; LCSC C19666
C5, C6, C8, C9: 10uF; C_0805_2012Metric; LCSC C380332
CHG1: LED; LED_0603_1608Metric; LCSC C2286
J1: JST-SH; JST_SH_SM04B-SRSS-TB_1x04-1MP_P1.00mm_Horizontal; LCSC C7527619
J2: Conn_01x08_Socket; PinSocket_1x08_P2.54mm_Vertical; not fitted
J3: JST-PH; JST_PH_S2B-PH-SM4-TB_1x02-1MP_P2.00mm_Horizontal; LCSC C968533
J4: USB_C_Receptacle_PowerOnly_6P; TYPE-C-SMD_TYPE-C-6P_1; LCSC C456012
Power1: SW_SPDT; SW-SMD_MST-12D18G4-SPDT-SLIDE-SWITCH; LCSC C49023767
Q1: 2N7002; SOT-23; LCSC C8545
R1: 10K; R_0402_1005Metric; LCSC C25744
R2: 4.7K; R_0402_1005Metric; LCSC C25900
R3, R4: 2.2K; R_0402_1005Metric; LCSC C25879
R5, R6: 5K1; R_0402_1005Metric; LCSC C25905
R7: 4K99; R_0402_1005Metric; LCSC C25903
R8: 2K; R_0402_1005Metric; LCSC C4109
R9: 100; R_0402_1005Metric; LCSC C25076
R10: 100K; R_0402_1005Metric; LCSC C25741
RST1: SW_Push; KEY-SMD_4P-L4.2-W3.2-P2.20-LS4.6; LCSC C139797
STAT1: LED; LED_0603_1608Metric; LCSC C12624
TP1: SWDIO; TestPoint_THTPad_D1.0mm_Drill0.5mm
TP2: SWCLK; TestPoint_THTPad_D1.0mm_Drill0.5mm
TP3: GND; TestPoint_THTPad_D1.0mm_Drill0.5mm
U1: STM32G030F6Px; TSSOP-20_4.4x6.5mm_P0.65mm; LCSC C724040
U2: KXTJ3-1057; Kionix_LGA-12_2x2mm_P0.5mm_LayoutBorder2x4y; LCSC C442603
U3: MCP73831-2-OT; SOT-23-5; LCSC C424093
U4: AP2112K-3.3; SOT-23-5; LCSC C51118

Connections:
/BL: J2.8, Q1.3 (D)
/CS: J2.7, U1.7 (PA0)
/DC: J2.6, U1.8 (PA1)
/PA2_TX: J1.3, J2.5, U1.9 (PA2)
/PA3_RX: J1.4, U1.10 (PA3)
/SCL: J2.3, U1.12 (PA5)
/SDA: J2.4, U1.14 (PA7)
/SWDIO: TP1.1, U1.18 (PA13)
/VCC: BOOT1.2, C1.1, C2.1, C4.1, C7.1, C9.1, J1.2, J2.2, R3.1, R4.1, STAT1.2 (A), U1.4 (VDD), U2.3 (IO_VDD), U2.7 (VDD), U2.10 (VDD), U2.11 (IO_VDD), U4.5 (VOUT)
GND: C1.2, C2.2, C3.2, C4.2, C5.2, C6.2, C7.2, C8.2, C9.2, J1.1, J2.1, J3.2, J4.A12 (GND), J4.B12 (GND), J4.S1 (SHIELD), Q1.2 (S), R1.2, R5.2, R6.2, R7.2, R10.2, RST1.1, TP3.1, U1.5 (VSS), U2.1 (ADDR), U2.4 (RES), U2.6 (GND), U2.8 (GND), U2.9 (GND), U3.2 (V_{SS}), U4.2 (GND)
unnamed: C5.1, CHG1.2 (A), J4.A9 (VBUS), J4.B9 (VBUS), U3.4 (V_{DD})
unnamed: CHG1.1 (K), R8.2
unnamed: C6.1, J3.1, Power1.2 (B), U3.3 (V_{BAT})
unnamed: J4.A5 (CC1), R6.1
unnamed: J4.B5 (CC2), R5.1
unnamed: C8.1, Power1.1 (A), U4.1 (VIN), U4.3 (EN)
unnamed: Q1.1 (G), R9.2
unnamed: R2.1, STAT1.1 (K)
unnamed: C3.1, RST1.2, U1.6 (NRST)
unnamed: U1.11 (PA4), U2.5 (INT)
unnamed: R2.2, R9.1, R10.1, U1.15 (PA8/PB0/PB1/PB2)
unnamed: BOOT1.1, R1.1, TP2.1, U1.19 (PA14/PA15)
unnamed: R3.2, U1.20 (PB3/PB4/PB5/PB6), U2.12 (SCL)
unnamed: R4.2, U1.1 (PB7/PB8), U2.2 (SDA)
unnamed: R7.1, U3.5 (PROG)
unnamed: R8.1, U3.1 (STAT)

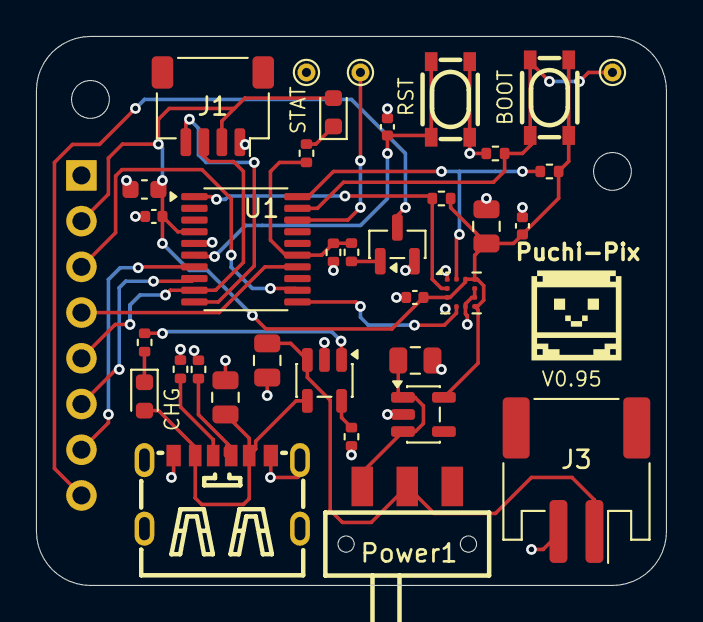
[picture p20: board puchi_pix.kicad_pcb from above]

Board: 2 copper layers, 35.0 x 30.5 mm, 36 parts (1 on the bottom side), 26 nets.

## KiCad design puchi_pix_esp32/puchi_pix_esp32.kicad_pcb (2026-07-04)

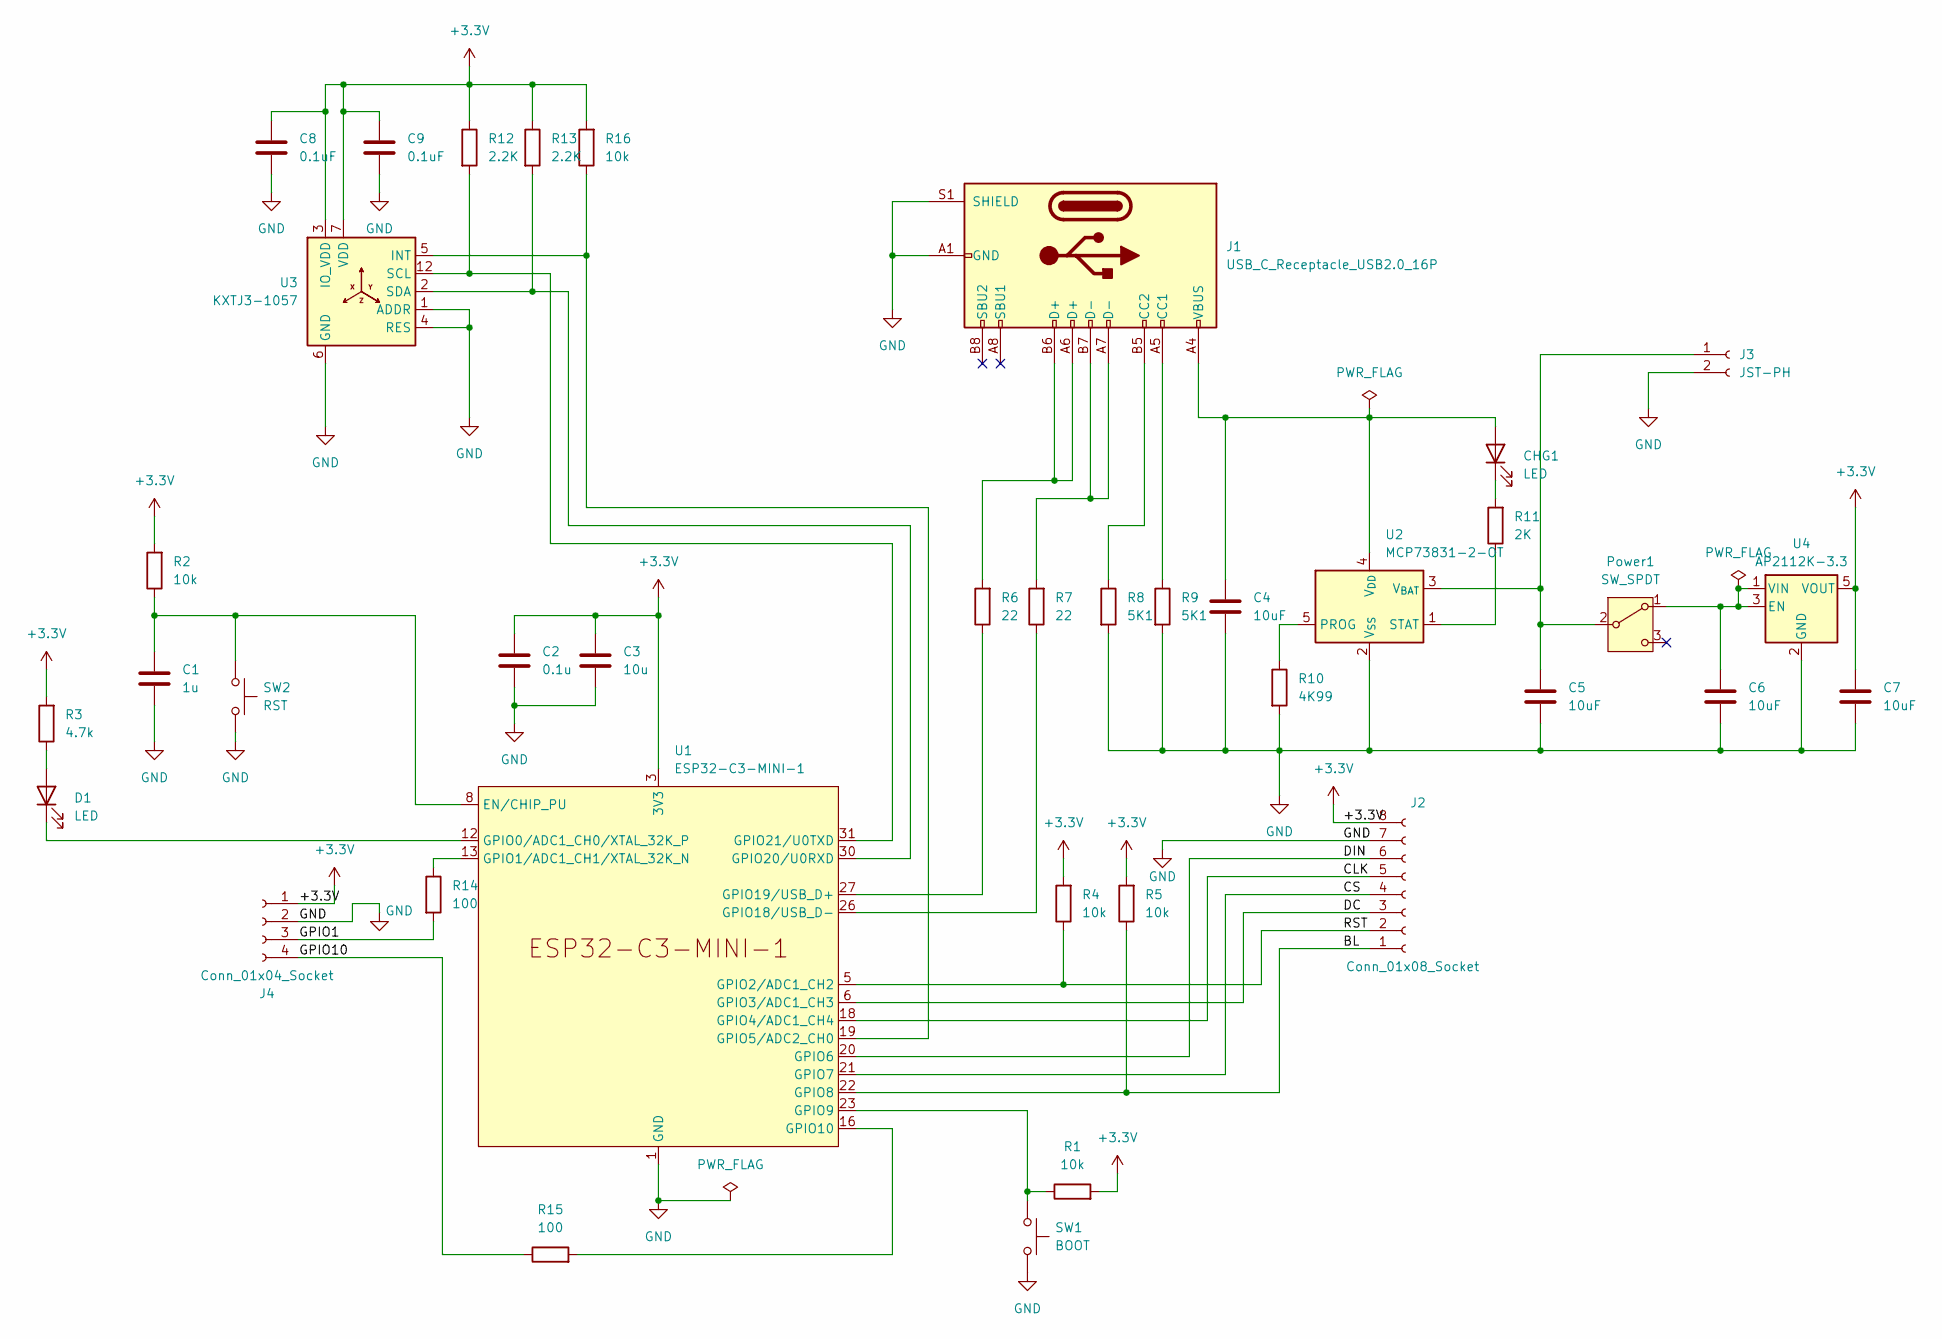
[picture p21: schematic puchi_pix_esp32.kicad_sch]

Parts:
C1: 1u; C_0402_1005Metric; LCSC C52923
C2: 0.1u; C_0402_1005Metric; LCSC C309458
C3: 10u; C_0805_2012Metric; LCSC C380332
C4, C5, C6, C7: 10uF; C_0805_2012Metric; LCSC C380332
C8, C9: 0.1uF; C_0402_1005Metric; LCSC C309458
CHG1: LED; LED_0603_1608Metric; LCSC C2286
D1: LED; LED_0603_1608Metric; LCSC C12624
J1: USB_C_Receptacle_USB2.0_16P; USB_C_Receptacle_HRO_TYPE-C-31-M-12; LCSC C165948
J2: Conn_01x08_Socket; PinSocket_1x08_P2.00mm_Vertical
J3: JST-PH; JST_PH_S2B-PH-SM4-TB_1x02-1MP_P2.00mm_Horizontal; LCSC C968533
J4: Conn_01x04_Socket; PinSocket_1x04_P2.54mm_Vertical
Power1: SW_SPDT; SW-SMD_MST-12D18G4-SPDT-SLIDE-SWITCH; LCSC C49023767
R1, R2, R4, R5, R16: 10k; R_0402_1005Metric; LCSC C25744
R3: 4.7k; R_0402_1005Metric; LCSC C25900
R6, R7: 22; R_0402_1005Metric; LCSC C25092
R8, R9: 5K1; R_0402_1005Metric; LCSC C25905
R10: 4K99; R_0402_1005Metric; LCSC C25903
R11: 2K; R_0402_1005Metric; LCSC C4109
R12, R13: 2.2K; R_0402_1005Metric; LCSC C25879
R14, R15: 100; R_0402_1005Metric; LCSC C25076
SW1: BOOT; KEY-SMD_4P-L4.2-W3.2-P2.20-LS4.6; LCSC C139797
SW2: RST; KEY-SMD_4P-L4.2-W3.2-P2.20-LS4.6; LCSC C139797
U1: ESP32-C3-MINI-1; LCSC C2838502
U2: MCP73831-2-OT; SOT-23-5; LCSC C424093
U3: KXTJ3-1057; Kionix_LGA-12_2x2mm_P0.5mm_LayoutBorder2x4y; LCSC C442603
U4: AP2112K-3.3; SOT-23-5; LCSC C51118

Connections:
+3.3V: C2.1, C3.1, C7.1, C8.1, C9.1, J2.8, J4.1, R1.2, R2.2, R3.2, R4.2, R5.2, R12.1, R13.1, R16.2, U1.3 (3V3), U3.3 (IO_VDD), U3.7 (VDD), U3.10 (VDD), U3.11 (IO_VDD), U4.5 (VOUT)
/BL: J2.1, R5.1, U1.22 (GPIO8)
/CLK: J2.5, U1.18 (GPIO4/ADC1_CH4)
/CS: J2.4, U1.21 (GPIO7)
/DC: J2.3, U1.6 (GPIO3/ADC1_CH3)
/DIN: J2.6, U1.20 (GPIO6)
/GPIO1: J4.3, R14.2
/GPIO10: J4.4, R15.1
/RST: J2.2, R4.1, U1.5 (GPIO2/ADC1_CH2)
GND: C1.2, C2.2, C3.2, C4.2, C5.2, C6.2, C7.2, C8.2, C9.2, J1.A1 (GND), J1.A12 (GND), J1.B1 (GND), J1.B12 (GND), J1.S1 (SHIELD), J2.7, J3.2, J4.2, R8.2, R9.2, R10.2, SW1.2, SW2.2, U1.1 (GND), U1.2 (GND), U1.11 (GND), U1.14 (GND), U1.36 (GND), U1.37 (GND), U1.38 (GND), U1.39 (GND), U1.40 (GND), U1.41 (GND), U1.42 (GND), U1.43 (GND), U1.44 (GND), U1.45 (GND), U1.46 (GND), U1.47 (GND), U1.48 (GND), U1.49 (GND), U1.50 (GND), U1.51 (GND), U1.52 (GND), U1.53 (GND), U2.2 (V_{SS}), U3.1 (ADDR), U3.4 (RES), U3.6 (GND), U3.8 (GND), U3.9 (GND), U4.2 (GND)
unnamed: C4.1, CHG1.2 (A), J1.A4 (VBUS), J1.A9 (VBUS), J1.B4 (VBUS), J1.B9 (VBUS), U2.4 (V_{DD})
unnamed: CHG1.1 (K), R11.2
unnamed: D1.2 (A), R3.1
unnamed: D1.1 (K), U1.12 (GPIO0/ADC1_CH0/XTAL_32K_P)
unnamed: J1.A5 (CC1), R9.1
unnamed: J1.B5 (CC2), R8.1
unnamed: J1.A6 (D+), J1.B6 (D+), R6.2
unnamed: J1.A7 (D-), J1.B7 (D-), R7.2
unnamed: C5.1, J3.1, Power1.2 (B), U2.3 (V_{BAT})
unnamed: C6.1, Power1.1 (A), U4.1 (VIN), U4.3 (EN)
unnamed: C1.1, R2.1, SW2.1, U1.8 (EN/CHIP_PU)
unnamed: R14.1, U1.13 (GPIO1/ADC1_CH1/XTAL_32K_N)
unnamed: R16.1, U1.19 (GPIO5/ADC2_CH0), U3.5 (INT)
unnamed: R1.1, SW1.1, U1.23 (GPIO9)
unnamed: R15.2, U1.16 (GPIO10)
unnamed: R7.1, U1.26 (GPIO18/USB_D-)
unnamed: R6.1, U1.27 (GPIO19/USB_D+)
unnamed: R13.2, U1.30 (GPIO20/U0RXD), U3.2 (SDA)
unnamed: R12.2, U1.31 (GPIO21/U0TXD), U3.12 (SCL)
unnamed: R10.1, U2.5 (PROG)
unnamed: R11.1, U2.1 (STAT)

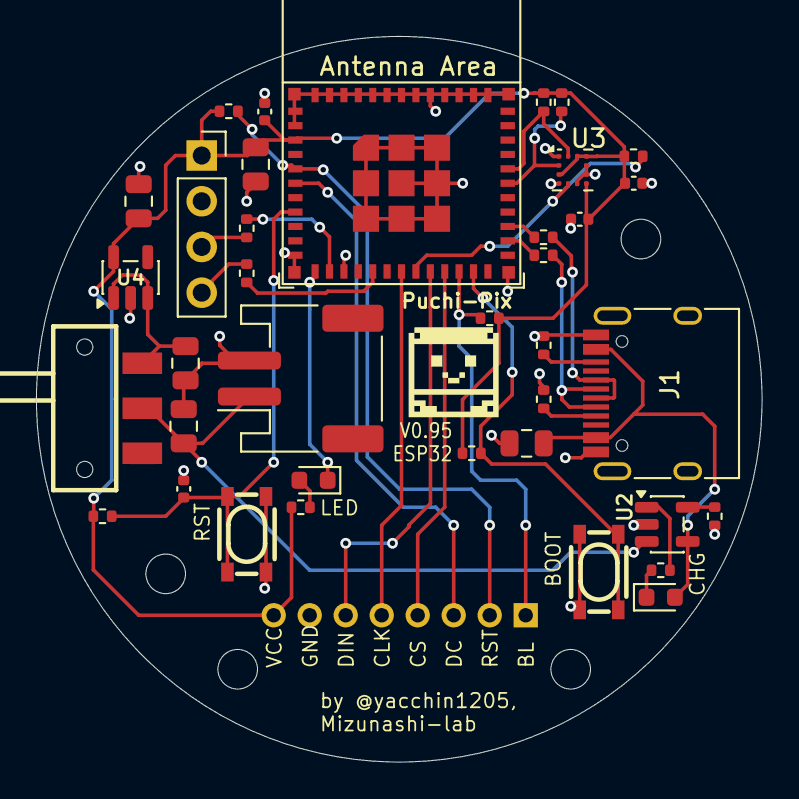
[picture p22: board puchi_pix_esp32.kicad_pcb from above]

Board: 2 copper layers, 40.3 x 40.3 mm, 38 parts (1 on the bottom side), 31 nets.

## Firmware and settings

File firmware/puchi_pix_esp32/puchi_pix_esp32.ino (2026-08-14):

// Puchi-Pix ESP32 (ESPr Developer C3): GC9A01 free-rotation viewer
// with BLE image upload
// 64-step (5.625deg) rotation following gravity tilt via KXTJ3.
// A BLE peripheral accepts a custom multi-frame image payload
// (GIF-converted) and swaps the active animation.
//
// BLE protocol:
//   Service:  5550EEC9-B00F-4444-9876-AB12CD34EF01
//   Upload  (Write):       5550EEC9-B00F-4444-9876-AB12CD34EF02
//   Commit  (Write):       5550EEC9-B00F-4444-9876-AB12CD34EF03
//   Status  (Read/Notify): 5550EEC9-B00F-4444-9876-AB12CD34EF04
//   Proto   (Read):        5550EEC9-B00F-4444-9876-AB12CD34EF06
//
//   Upload: chunked writes appended in order to a 32 KB buffer.
//   Commit: 0x01 = validate & swap, 0x02 = buffer reset, 0x03 = revert default.
//   Status: 1 byte (0=idle, 1=receiving, 2=success, 3=error).
//   Proto: 4 bytes [payloadVerMax, payloadVerMin, legacyMotionCfgLen,
//     reserved]. Read by the uploader on connect so a web/firmware protocol
//     mismatch is reported explicitly instead of failing as a generic
//     upload error. legacyMotionCfgLen is 0: since v6 the motion config is
//     embedded in the payload and the Motion characteristic is gone.
//   Motion block (16 bytes, embedded in v6 payloads):
//     [enabled, mainStart lo/hi, loopStart lo/hi, shakeStart lo/hi,
//      outStart lo/hi, exitStart lo/hi, speed, gap lo/hi, bg565 lo/hi].
//     Splits the animation into up to six segments:
//       entry walk  [0, mainStart)         loops while walking in
//       intro trans [mainStart, loopStart) plays once after arriving
//       main loop   [loopStart, shakeStart | outStart | exitStart | N)
//                                          loops while handling is detected
//       shake       [shakeStart, outStart | exitStart | N)
//                                          plays once when the device is
//                                          shaken during the main loop,
//                                          then the main loop resumes
//       outro trans [outStart, exitStart | N) plays once before leaving
//       exit walk   [exitStart, N)         loops while walking out
//     Sentinels: mainStart = 0 -> no entry walk (the main loop itself plays
//     while walking in/out; intro is forced off). loopStart <= mainStart ->
//     no intro. shakeStart = 0 -> no shake segment. outStart = 0 -> no
//     outro. exitStart = 0 -> exit reuses the entry walk frames (or the
//     main loop when there is no entry).
//     When enabled, the sprite walks in from the right translating at
//     `speed` source px/s, then the screen stays empty for `gap` ms after
//     the exit before the next entry. speed = 0 -> no walk: the sprite
//     appears and disappears in place (entry and a dedicated exit are
//     rejected as inconsistent with no walk). bg565 fills everything outside the
//     sprite (RGB565), matching the uploader's compositing background.
//     Because the block lives inside the payload, image and presentation
//     are committed, validated and persisted atomically (/img.bin only).
//
// Payload (sent via Upload, raw bytes appended in order):
//   v1 (64x64 fixed):
//     [0..1]  Magic 'PP' (0x50 0x50)
//     [2]     Version = 1
//     [3]     Frame count N (1..16)
//     [4..35] Palette: 16 x uint16 RGB565, little-endian (32 B)
//     [36..]  Per frame: uint16 duration_ms (LE) + data[2048] (4-bit packed)
//   v2 (64x64 or 128x128, 16 or 256 colors):
//     [0..1]  Magic 'PP'
//     [2]     Version = 2
//     [3]     Frame count N
//     [4]     Image width  (64 or 128)
//     [5]     Image height (must equal width)
//     [6]     Bits per pixel: 0 or 4 = 16-color, 8 = 256-color
//     [7]     Reserved (0)
//     [8..]   Palette: 16 (4bpp, 32 B) or 256 (8bpp, 512 B) x uint16 RGB565 LE
//     then    Per frame: uint16 duration_ms (LE) + data[W*H*bpp/8]
//             (4bpp: packed 2px/byte, even idx = high nibble; 8bpp: 1px/byte)
//   v3 (diff chain; 64x64, 120x120 or 128x128, 16 or 256 colors):
//     [0..1]  Magic 'PP'
//     [2]     Version = 3
//     [3..4]  Frame count N (uint16 LE, >= 1)
//     [5]     Image size (64, 120 or 128, square)
//     [6]     Bits per pixel: 4 = 16-color, 8 = 256-color
//     [7]     Reserved (0)
//     [8..]   Palette: 16 (4bpp, 32 B) or 256 (8bpp, 512 B) x uint16 RGB565 LE
//     then    Per frame: uint16 duration_ms (LE) + uint8 flags (bit0 = keyframe)
//             keyframe: data[W*H*bpp/8] (full frame)
//             diff:     uint8 rectCount + rectCount x
//                       { rx, ry, rw, rh (uint8) + data[ceil(rw*rh*bpp/8)] }
//             Diffs apply onto the previously composed frame; frame 0 must be
//             a keyframe. Playback is sequential and wraps to frame 0.
//   v4 (RLE diff chain): identical to v3 except every pixel-data block is
//     PackBits RLE compressed and prefixed with its uint16 LE byte length:
//     keyframe: uint16 rleLen + rle[rleLen]   (decodes to W*H*bpp/8 bytes)
//     rect:     rx, ry, rw, rh, uint16 rleLen + rle[rleLen]
//               (decodes to ceil(rw*rh*bpp/8) bytes)
//     PackBits: control c < 128 = copy next c+1 bytes verbatim; c > 128 =
//     repeat next byte (257 - c) times; c == 128 = no-op. 4bpp data is RLE'd
//     on the packed bytes.
//   v6: v5 with a 16-byte motion block between the header and the palette
//     (palette starts at byte 24); see "Motion block" above. Validated as
//     part of commit; v3-v5 payloads simply play as a plain loop.
//   v5: v4 plus referenced-diff records (flags bit1). Instead of diffing
//     against the previous frame, the rects patch a copy of an arbitrary
//     EARLIER frame; an exact repeat is simply a referenced diff with zero
//     rects:
//       uint16 duration + flags(0x02) + uint16 refFrame LE + uint8 rectCount
//       + rects (v4 layout)
//     To keep decode single-level, refFrame must itself be composable
//     without touching any referenced-diff record (its replay window from
//     the nearest keyframe contains none); validation enforces this and the
//     uploader only picks refs satisfying it.
//   v1/v2 frame count is additionally bounded by the upload buffer (98368 B):
//   64x64 -> 16 frames either depth; 128x128 -> 12 (16-color) / 5 (256-color).
//   v3/v4 have no fixed frame cap; the payload just has to fit the buffer.
//
// BLE is active only while awake. Deep-sleep entry stops the radio implicitly.
//
// Persistence: a successful commit writes the upload buffer to LittleFS at
// /img.bin. On boot, the file is loaded back and validated before showing.
// Revert (0x03) removes the file. Requires a partition scheme that includes
// a SPIFFS/LittleFS partition (e.g. "Minimal SPIFFS").

#include <SPI.h>
#include <Wire.h>
#include <esp_sleep.h>
#include <driver/gpio.h>
#include <LittleFS.h>
#include <BLEDevice.h>
#include <BLEServer.h>
#include <BLEUtils.h>
#include <BLE2902.h>

// ---- BLE constants ----
#define BLE_DEVICE_NAME       "puchi-pix"
#define BLE_SERVICE_UUID      "5550eec9-b00f-4444-9876-ab12cd34ef01"
#define BLE_UPLOAD_UUID       "5550eec9-b00f-4444-9876-ab12cd34ef02"
#define BLE_COMMIT_UUID       "5550eec9-b00f-4444-9876-ab12cd34ef03"
#define BLE_STATUS_UUID       "5550eec9-b00f-4444-9876-ab12cd34ef04"
#define BLE_PROTO_UUID        "5550eec9-b00f-4444-9876-ab12cd34ef06"

// Accelerometer diagnostics: define to add a BLE characteristic (…ef07,
// Read/Notify) streaming, every 200 ms, the window's max instantaneous
// deviation and orientation drift per axis plus the motion phase — for
// tuning HANDLE_DRIFT_THRESH / SHAKE_THRESH against measured noise. Off by
// default; the uploader subscribes and logs automatically when the
// characteristic exists.
// #define PUCHI_DIAG_ACCEL 1
#ifdef PUCHI_DIAG_ACCEL
#define BLE_DIAG_UUID         "5550eec9-b00f-4444-9876-ab12cd34ef07"
#endif

static constexpr uint8_t PAYLOAD_VER_MIN = 1;
static constexpr uint8_t PAYLOAD_VER_MAX = 6;

static constexpr uint8_t MAX_UPLOADED_FRAMES = 16;

static constexpr uint8_t STATUS_IDLE      = 0;
static constexpr uint8_t STATUS_RECEIVING = 1;
static constexpr uint8_t STATUS_SUCCESS   = 2;
static constexpr uint8_t STATUS_ERROR     = 3;

// Result of loadPersistedImage(). Declared up here so the Arduino auto-prototype
// generator sees the type before any function signatures that use it.
enum LoadResult : uint8_t {
  LOAD_OK       = 0,  // image restored
  LOAD_NONE     = 1,  // no persisted image (first boot / after revert)
  LOAD_FS_FAIL  = 2,  // filesystem mount or read failure
  LOAD_INVALID  = 3,  // file exists but is corrupt / wrong format
};

// PackBits reader emitting one decoded byte per call (v4 payloads). The
// stream is validated up front, so no bounds checks during decode. Declared
// up here for the same auto-prototype reason as LoadResult.
struct RleReader {
  const uint8_t* p;
  uint8_t runByte;
  uint8_t runLeft;
  uint8_t litLeft;
};

// Motion (walk-in/out) configuration; see the Motion characteristic notes in
// the header comment. Declared up here for the auto-prototype generator.
struct MotionConfig {
  uint8_t  enabled;    // 0 = plain in-place loop (legacy behavior)
  uint16_t mainStart;  // end of entry walk = start of intro; 0 = no entry
  uint16_t loopStart;  // first frame of the main loop; <= mainStart = no intro
  uint16_t shakeStart; // first frame of the shake segment; 0 = none
  uint16_t outStart;   // first frame of the outro transition; 0 = none
  uint16_t exitStart;  // first frame of the exit walk; 0 = reuse entry
  uint8_t  speed;      // traverse speed, source px/s
  uint16_t gapMs;      // empty-screen time after exit before re-entry
  uint16_t bg;         // RGB565 fill outside the sprite / for empty screen
};

// ---- Pin assignments ----
static constexpr uint8_t TFT_SCK  = 4;
static constexpr uint8_t TFT_MOSI = 6;
static constexpr uint8_t TFT_CS   = 7;
static constexpr uint8_t TFT_DC   = 3;
static constexpr uint8_t TFT_RST  = 2;
static constexpr uint8_t TFT_BL   = 8;

static constexpr uint8_t I2C_SDA  = 20;
static constexpr uint8_t I2C_SCL  = 21;
static constexpr uint8_t KXTJ3_INT_PIN = 5;

// Status LED D1: 3.3V -> 4.7k -> LED -> GPIO0, so LOW = lit. Blinks for a
// second whenever (debounced) handling detection fires — the events that
// keep the device awake and trigger walk-ins — so spurious accelerometer
// activity is visible on a stationary device.
static constexpr uint8_t STATUS_LED = 0;

static constexpr int WIDTH  = 240;
static constexpr int HEIGHT = 240;

// ---- Default image data (PROGMEM fallback) ----
#include "../puchi_pix/frame.h"
#include "../puchi_pix/icon_original.h"

static constexpr uint16_t MAX_IMG_SIZE = 128;

// 12 frames of 128x128 (or 16 of 64x64) + v2 header. Kept below the full
// 16x128x128 (131 KB) so enough heap remains for the Bluedroid BLE stack.
static constexpr size_t UPLOAD_BUF_SIZE = 8 + 32 + 12u * ((size_t)MAX_IMG_SIZE * MAX_IMG_SIZE / 2 + 2);  // 98368

// All sources are pixel-doubled (shift 1).
// 64x64  -> 128x128 visible; rotated corners sweep a 181px diagonal, so the
//           output window is 192x192 (black outside the sprite erases trails).
// 120x120 -> 240x240 visible, exactly filling the window. The 240px disc is
//           the square's inscribed circle (radius 120 = half-side) at every
//           rotation angle, so nothing is cropped and no black corners appear.
// 128x128 -> 256x256 visible, cropped to the full 240x240 window. Its inscribed
//           circle (256px) always covers the 240px disc, so no black corners
//           and every visible pixel maps inside the source (radius 120/2 = 60 < 64).
static constexpr uint8_t SCALE_SHIFT = 1;

// Active source dimensions (updated when the image source switches)
static uint8_t srcSize  = IMG_W;  // 64, 120 or 128
static int16_t outSize  = 192;    // output window: 192 (64src) or 240 (120/128src)

// ---- 64-step rotation table (Q15) ----
static const int16_t COS64[64] = {
   32767,  32610,  32138,  31357,  30274,  28898,  27246,  25330,
   23170,  20788,  18205,  15447,  12540,   9512,   6393,   3212,
       0,  -3212,  -6393,  -9512, -12540, -15447, -18205, -20788,
  -23170, -25330, -27246, -28898, -30274, -31357, -32138, -32610,
  -32767, -32610, -32138, -31357, -30274, -28898, -27246, -25330,
  -23170, -20788, -18205, -15447, -12540,  -9512,  -6393,  -3212,
       0,   3212,   6393,   9512,  12540,  15447,  18205,  20788,
   23170,  25330,  27246,  28898,  30274,  31357,  32138,  32610,
};
static const int16_t SIN64[64] = {
       0,   3212,   6393,   9512,  12540,  15447,  18205,  20788,
   23170,  25330,  27246,  28898,  30274,  31357,  32138,  32610,
   32767,  32610,  32138,  31357,  30274,  28898,  27246,  25330,
   23170,  20788,  18205,  15447,  12540,   9512,   6393,   3212,
       0,  -3212,  -6393,  -9512, -12540, -15447, -18205, -20788,
  -23170, -25330, -27246, -28898, -30274, -31357, -32138, -32610,
  -32767, -32610, -32138, -31357, -30274, -28898, -27246, -25330,
  -23170, -20788, -18205, -15447, -12540,  -9512,  -6393,  -3212,
};

// ---- SPI helpers ----

static inline void cmdByte(uint8_t cmd) {
  digitalWrite(TFT_DC, LOW);
  digitalWrite(TFT_CS, LOW);
  SPI.transfer(cmd);
  digitalWrite(TFT_CS, HIGH);
}

static inline void cmdWithData(uint8_t cmd, const uint8_t* data, uint8_t n) {
  digitalWrite(TFT_CS, LOW);
  digitalWrite(TFT_DC, LOW);
  SPI.transfer(cmd);
  if (n) {
    digitalWrite(TFT_DC, HIGH);
    while (n--) SPI.transfer(*data++);
  }
  digitalWrite(TFT_CS, HIGH);
}

// ---- GC9A01 init ----

static void gc9a01Init() {
  static const uint8_t initTable[] PROGMEM = {
    0xEF, 0,
    0xEB, 1, 0x14,
    0xFE, 0,
    0xEF, 0,
    0xEB, 1, 0x14,
    0x84, 1, 0x40,  0x85, 1, 0xFF,  0x86, 1, 0xFF,  0x87, 1, 0xFF,
    0x88, 1, 0x0A,  0x89, 1, 0x21,  0x8A, 1, 0x00,  0x8B, 1, 0x80,
    0x8C, 1, 0x01,  0x8D, 1, 0x01,  0x8E, 1, 0xFF,  0x8F, 1, 0xFF,
    0xB6, 2, 0x00, 0x00,
    0x36, 1, 0x48,
    0x3A, 1, 0x05,
    0x90, 4, 0x08, 0x08, 0x08, 0x08,
    0xBD, 1, 0x06,  0xBC, 1, 0x00,
    0xFF, 3, 0x60, 0x01, 0x04,
    0xC3, 1, 0x13,  0xC4, 1, 0x13,  0xC9, 1, 0x22,  0xBE, 1, 0x11,
    0xE1, 2, 0x10, 0x0E,
    0xDF, 3, 0x21, 0x0C, 0x02,
    0xF0, 6, 0x45, 0x09, 0x08, 0x08, 0x26, 0x2A,
    0xF1, 6, 0x43, 0x70, 0x72, 0x36, 0x37, 0x6F,
    0xF2, 6, 0x45, 0x09, 0x08, 0x08, 0x26, 0x2A,
    0xF3, 6, 0x43, 0x70, 0x72, 0x36, 0x37, 0x6F,
    0xED, 2, 0x1B, 0x0B,
    0xAE, 1, 0x77,  0xCD, 1, 0x63,
    0x70, 9, 0x07, 0x07, 0x04, 0x0E, 0x0F, 0x09, 0x07, 0x08, 0x03,
    0xE8, 1, 0x34,
    0x62, 12, 0x18, 0x0D, 0x71, 0xED, 0x70, 0x70, 0x18, 0x0F, 0x71, 0xEF, 0x70, 0x70,
    0x63, 12, 0x18, 0x11, 0x71, 0xF1, 0x70, 0x70, 0x18, 0x13, 0x71, 0xF3, 0x70, 0x70,
    0x64, 7, 0x28, 0x29, 0xF1, 0x01, 0xF1, 0x00, 0x07,
    0x66, 10, 0x3C, 0x00, 0xCD, 0x67, 0x45, 0x45, 0x10, 0x00, 0x00, 0x00,
    0x67, 10, 0x00, 0x3C, 0x00, 0x00, 0x00, 0x01, 0x54, 0x10, 0x32, 0x98,
    0x74, 7, 0x10, 0x85, 0x80, 0x00, 0x00, 0x4E, 0x00,
    0x98, 2, 0x3E, 0x07,
    0x35, 0,
    0x21, 0,
    0x11, 0x80, 120,
    0x29, 0x80, 20,
  };
  const uint8_t* p = initTable;
  const uint8_t* end = initTable + sizeof(initTable);
  while (p < end) {
    uint8_t cmd = pgm_read_byte(p++);
    uint8_t nd = pgm_read_byte(p++);
    uint8_t n = nd & 0x7F;
    uint8_t buf[12];
    for (uint8_t i = 0; i < n; i++) buf[i] = pgm_read_byte(p++);
    cmdWithData(cmd, buf, n);
    if (nd & 0x80) delay(pgm_read_byte(p++));
  }
}

// ---- Drawing primitives ----
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
void loop() {
  uint32_t now = millis();
  digitalWrite(STATUS_LED, (now - handleLedMs < 1000) ? LOW : HIGH);

#ifdef PUCHI_DIAG_ACCEL
  if (pDiagChar && now - diagNotifyMs >= 200) {
    diagNotifyMs = now;
    uint8_t d[10] = {
      (uint8_t)diagMaxAdx, (uint8_t)(((uint32_t)diagMaxAdx >> 8) & 0xFF),
      (uint8_t)diagMaxAdy, (uint8_t)(((uint32_t)diagMaxAdy >> 8) & 0xFF),
      (uint8_t)diagMaxDdx, (uint8_t)(((uint32_t)diagMaxDdx >> 8) & 0xFF),
      (uint8_t)diagMaxDdy, (uint8_t)(((uint32_t)diagMaxDdy >> 8) & 0xFF),
      (uint8_t)motionPhase,
      (uint8_t)(diagDetected ? 1 : 0),
    };
    pDiagChar->setValue(d, 10);
    pDiagChar->notify();
    diagMaxAdx = diagMaxAdy = diagMaxDdx = diagMaxDdy = 0;
    diagDetected = false;
  }
#endif

  // Display power. With a motion payload the presentation state machine is
  // the authority: active phases run at full brightness however long they
  // take, and GAP (exit finished = absence confirmed) dims immediately and
  // deep sleeps after GAP_SLEEP_MS. Without a state machine the classic
  // inactivity timer decides. A connected host or an in-flight transfer
  // suppresses sleep in both modes.
  bool busy = bleConnected || uploadStatus == STATUS_RECEIVING;
  if (busy) lastActivityMs = now;
  bool dim;
  bool sleepNow;
  if (motionOn()) {
    bool gap = (motionPhase == PH_GAP);
    dim = gap;
    sleepNow = gap && !busy && (now - gapEnteredMs >= GAP_SLEEP_MS);
  } else {
    uint32_t elapsed = now - lastActivityMs;
    dim = (elapsed >= DIM_TIMEOUT_MS);
    sleepNow = (elapsed >= SLEEP_TIMEOUT_MS);
  }
  if (sleepNow) {
    displayOff();
    clearLatchedInterrupt();
    esp_deep_sleep_start();
  }
  analogWrite(TFT_BL, dim ? 40 : 255);

  // Apply pending image source switch (commit or revert). The motion config
  // indexes frames of the previous payload, so it is cleared here; the
  // uploader re-sends it after a commit if the user wants motion.
  if (uploadCommittedFlag) {
    uploadCommittedFlag = false;
    adoptPayloadMotion();
    lastFrameTime = now;
    motionLastMs = now;
    fillScreen(motionCfg.bg);  // clear stale pixels outside the new window
    if (motionOn()) {
      // Start hidden; seed the handling timer so the sprite walks in right
      // away (a fresh commit implies the user is present).
      motionPhase = PH_GAP;
      gapReadyMs = now;
      gapEnteredMs = now;
      lastHandledMs = now;
    } else {
      animReset();
      drawFrameRotated(frameBuf, currentBin, 0);
    }
  }

  // Apply pending persistence operations (deferred from BLE callbacks so the
  // BLE task isn't blocked by Flash writes).
  if (persistRequested) {
    persistRequested = false;
    if (!persistImage()) setStatus(STATUS_ERROR);
  }
  if (clearPersistRequested) {
    clearPersistRequested = false;
    if (!clearPersistedImage()) setStatus(STATUS_ERROR);
  }

  // Update lowpass on raw gravity vector. Blend factor is dt/tau so the
  // effective time constant stays ~LP_TAU_MS whether the loop is spinning
  // at sub-ms (no redraw) or stalled tens of ms by a frame write.
  int16_t rx, ry, rz;
  if (readXYZRaw(rx, ry, rz)) {
    int32_t fx = (int32_t)rx * ACCEL_X_SIGN;
    int32_t fy = (int32_t)ry * ACCEL_Y_SIGN;
    int32_t adx = labs(fx - fxLp);              // instantaneous dev (shake)
    int32_t ady = labs(fy - fyLp);
    int32_t ddx = labs(fxLpFP - fxSlowFP) >> 8; // orientation drift (handling)
    int32_t ddy = labs(fyLpFP - fySlowFP) >> 8;
#ifdef PUCHI_DIAG_ACCEL
    if (adx > diagMaxAdx) diagMaxAdx = adx;
    if (ady > diagMaxAdy) diagMaxAdy = ady;
    if (ddx > diagMaxDdx) diagMaxDdx = ddx;
    if (ddy > diagMaxDdy) diagMaxDdy = ddy;
#endif
    // Handling: the fast lowpass drifting away from the slow reference.
    // Counts as activity (keeps the display awake).
    if (ddx > HANDLE_DRIFT_THRESH || ddy > HANDLE_DRIFT_THRESH) {
      if (handleStreak < HANDLE_DEBOUNCE) handleStreak++;
    } else {
      handleStreak = 0;
    }
    if (handleStreak >= HANDLE_DEBOUNCE) {
      lastHandledMs = now;
      lastActivityMs = now;
      handleLedMs = now;
#ifdef PUCHI_DIAG_ACCEL
      diagDetected = true;
#endif
    }
    // Shake: sustained instantaneous spikes far above the rest noise.
    if (adx > SHAKE_THRESH || ady > SHAKE_THRESH) {
      if (shakeStreak < SHAKE_DEBOUNCE) shakeStreak++;
    } else {
      shakeStreak = 0;
    }
    if (shakeStreak >= SHAKE_DEBOUNCE) {
      lastHandledMs = now;                // shaking is handling, too
      lastActivityMs = now;
      if (motionOn() && motionPhase == PH_MAIN && hasShakeSeg()) {
        shakePending = true;
      }
    }
    int32_t dt = (int32_t)(now - lastLpUpdateMs);
    if (dt > 0) {
      lastLpUpdateMs = now;
      int32_t dtF = (dt > LP_TAU_MS) ? LP_TAU_MS : dt;
      fxLpFP += (int32_t)(((int64_t)((fx << 8) - fxLpFP) * dtF) / LP_TAU_MS);
      fyLpFP += (int32_t)(((int64_t)((fy << 8) - fyLpFP) * dtF) / LP_TAU_MS);
      fxLp = fxLpFP >> 8;
      fyLp = fyLpFP >> 8;
      int32_t dtS = (dt > LP_SLOW_TAU_MS) ? LP_SLOW_TAU_MS : dt;
      fxSlowFP += (int32_t)(((int64_t)(fxLpFP - fxSlowFP) * dtS) / LP_SLOW_TAU_MS);
      fySlowFP += (int32_t)(((int64_t)(fyLpFP - fySlowFP) * dtS) / LP_SLOW_TAU_MS);
    }
  }

  int32_t mag2 = fxLp * fxLp + fyLp * fyLp;
  if (mag2 > MAG2_MIN) {
    curAbsBin = computeBin(fxLp, fyLp, curAbsBin);
  }
  int8_t diff = (int8_t)curAbsBin - (int8_t)MOUNT_NEUTRAL_BIN;
  diff *= BIN_DIR_SIGN;
  uint8_t newBin = (uint8_t)diff & 0x3F;

  bool binChanged = (newBin != currentBin);
  if (binChanged) {
    currentBin = newBin;
    lastActivityMs = now;
  }

  if (motionOn()) {
    runMotion(now, binChanged);
    return;
  }

  uint16_t duration = getDuration(curFrame);
  bool frameAdvance = (now - lastFrameTime >= duration);
  if (frameAdvance) {
    lastFrameTime = now;
    animAdvance();
  }

  if (frameAdvance || binChanged) {
    drawFrameRotated(frameBuf, currentBin, 0);
  }
}

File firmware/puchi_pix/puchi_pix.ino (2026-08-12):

// NOTE: Build with "Tools > U(S)ART support > Disabled" to fit in 32KB flash
#include <Arduino.h>
#include <Wire.h>
#include <SPI.h>

// =====================
// 画像データ (アイコン差し替えはここだけ変更)
// =====================
#include "frame.h"
#include "icon_original.h"

#ifndef HAS_WALK
#error "icon header predates frame roles; regenerate with resources/generate_image_data.py"
#endif

// =====================
// ディスプレイ抽象化レイヤー
// =====================
#include "display.h"

// デバッグ: loopカウンタをY=0に表示
#define DEBUG_LOOP_COUNTER 0

// 手持ち検出診断: ドリフト量をY=0(X軸)/Y=1(Y軸)にバー表示。
// 閾値=白ティック(x=32)、検出中=右端赤。リリースビルドでは0にする。
#define PUCHI_DIAG_HANDLE 0

// 上方向インジケーター (赤ドット)。フラッシュ節約のためデフォルト無効
#define ENABLE_UP_INDICATOR 0

#if DEBUG_LOOP_COUNTER
static uint16_t dbgLoopCount = 0;

static void drawDebugCounter() {
  uint8_t barLen = dbgLoopCount % DISPLAY_W;
  displayBeginWrite(0, 0, DISPLAY_W, 1);
  for (uint8_t x = 0; x < DISPLAY_W; x++) {
    displayWritePixel(x < barLen ? 0x07E0 : 0x0000);
  }
  displayEndWrite();
}
#endif

// =====================
// KXTJ3 (I2C)
// =====================
static const uint8_t KXTJ3_ADDR     = 0x0E;
static const uint8_t REG_CTRL1      = 0x1B;
static const uint8_t REG_CTRL2      = 0x1D;
static const uint8_t REG_INT_CTRL1  = 0x1E;
static const uint8_t REG_INT_CTRL2  = 0x1F;
static const uint8_t REG_DATA_CTRL  = 0x21;
static const uint8_t REG_XOUT_L     = 0x06;
static const uint8_t REG_INT_REL    = 0x1A;
static const uint8_t REG_WU_COUNTER = 0x29;
static const uint8_t REG_WUTH_H     = 0x6A;
static const uint8_t REG_WUTH_L     = 0x6B;

static constexpr uint32_t KXTJ3_INT_PIN = PA_4;

// 加速度センサー座標反転
static constexpr int ACCEL_X_SIGN = 1;
static constexpr int ACCEL_Y_SIGN = 1;

// 向き変更後のクールダウン
static constexpr uint32_t ORIENT_COOLDOWN_MS = 1500;
static uint32_t lastOrientChangeMs = 0;
static int8_t pendingOrient = -1;

// アニメーション状態
static uint8_t  curFrame = 0;
static int8_t   lastDrawnFrame = -1;
static uint8_t  currentOrient = 0;
static uint32_t lastFrameTime = 0;

// =====================
// 歩き登場アニメーション
// 右から歩いて入場 → 中割り(入り) → メインループ → 中割り(戻り) → 左へ歩いて退場
// メインは手持ち検出が続く間ループし、ループ境界で退場側へ抜ける。
// =====================
// フレーム役割 (WALK_SEQ / FRAME_INTRO_START / FRAME_MAIN_START /
// FRAME_OUTRO_START) はアイコンヘッダが定義する。FRAME_NONE は省略。
// introチェーンは curFrame が FRAME_MAIN_START に達したところで終端。
// mainチェーンは FRAME_MAIN_START に戻る循環。
// outroチェーンは next が WALK_SEQ[0] に戻ったところで終端。
static uint8_t walkPhase = 0;  // WALK_SEQ内の現在位置

static constexpr int16_t  WALK_CENTER_X = (DISPLAY_W - IMG_W) / 2;
static constexpr int16_t  WALK_ENTER_X  = DISPLAY_W;   // 右端の画面外
static constexpr int16_t  WALK_EXIT_X   = -IMG_W;      // 左端の画面外
static constexpr uint8_t  WALK_STEP_PX  = 4;
static constexpr uint16_t WALK_STEP_MS  = 150;
static constexpr uint16_t WALK_PAUSE_MS = 800;         // 退場後、再入場までの待ち

enum WalkMode : uint8_t {
  MODE_WALK_IN, MODE_INTRO, MODE_MAIN, MODE_OUTRO, MODE_WALK_OUT, MODE_OFFSCREEN
};
static uint8_t walkMode = MODE_WALK_IN;
static int16_t spriteX  = WALK_ENTER_X;  // 見た目上のX位置 (orient 3では鏡映して描画)

// ---------- KXTJ3 low-level ----------
static inline void write8(uint8_t reg, uint8_t val) {
  Wire.beginTransmission(KXTJ3_ADDR);
  Wire.write(reg);
  Wire.write(val);
  Wire.endTransmission(true);
}

// ---------- Display Power / Sleep ----------
// HAS_WALK: フェーズ駆動。退場後(OFFSCREEN)は即減光し、OFFSCREEN_SLEEP_MS
// でスリープ。再生中は減光しない。
// 単純ループ (HAS_WALK 0): 従来どおり lastActivityMs からのタイマー駆動。
static constexpr uint32_t DIM_TIMEOUT_MS      = 10000;
static constexpr uint32_t SLEEP_TIMEOUT_MS    = 30000;
static constexpr uint32_t OFFSCREEN_SLEEP_MS  = 10000;

static uint32_t lastActivityMs = 0;
static uint32_t offscreenEnterMs = 0;

static void setWakeupThreshold(uint16_t counts12) {
  counts12 &= 0x0FFF;
  write8(REG_WUTH_H, (counts12 >> 4) & 0xFF);
  write8(REG_WUTH_L, (counts12 & 0x0F) << 4);
}

static void clearLatchedInterrupt() {
  Wire.beginTransmission(KXTJ3_ADDR);
  Wire.write(REG_INT_REL);
  Wire.endTransmission(false);
  Wire.requestFrom(KXTJ3_ADDR, (uint8_t)1);
  (void)Wire.read();
}

// 分解能切り替え。手持ち検出には12bitが必要 (8bitは1LSB≈256カウントで、
// 手持ちの微小ドリフトが量子化に埋もれて検出が続かない)。スリープ中は
// 省電力の8bitに戻す (12bit: 155µA / 8bit: 10µA)。ウェイク機能の
// サンプリングはOWUF (CTRL2) 独立なのでRESの影響を受けない。
static void setAccelHighRes(bool highRes) {
  write8(REG_CTRL1, 0x00); delay(10);
  write8(REG_CTRL1, highRes ? 0xC2 : 0x82); delay(50);
}

static void enableWakeupInterrupt() {
  write8(REG_CTRL1, 0x00); delay(10);
  write8(REG_CTRL2, 0x04);
  write8(REG_WU_COUNTER, 2);
  setWakeupThreshold(64);
  write8(REG_INT_CTRL2, 0x3F);
  write8(REG_INT_CTRL1, 0x20);
  write8(REG_CTRL1, 0xC2); delay(50);
  clearLatchedInterrupt();
}

void wakeupCallback() {
  lastActivityMs = millis();
}

// ---------- 図形描画 ----------
static void displayFillCircle(int x0, int y0, int rad, uint8_t r8, uint8_t g8, uint8_t b8) {
  if (rad <= 0) return;

  int f = 1 - rad;
  int ddF_x = 1;
  int ddF_y = -2 * rad;
  int x = 0;
  int y = rad;

  displayHLine(x0 - rad, y0, 2 * rad + 1, r8, g8, b8);

  while (x < y) {
    if (f >= 0) { y--; ddF_y += 2; f += ddF_y; }
    x++; ddF_x += 2; f += ddF_x;

    displayHLine(x0 - x, y0 + y, 2 * x + 1, r8, g8, b8);
    displayHLine(x0 - x, y0 - y, 2 * x + 1, r8, g8, b8);
    displayHLine(x0 - y, y0 + x, 2 * y + 1, r8, g8, b8);
    displayHLine(x0 - y, y0 - x, 2 * y + 1, r8, g8, b8);
  }
}

// ---------- Frame描画 ----------
// Orientation: 0=normal, 3=180°(逆さ)。90°(orient 1/2)は非対応。

static inline uint8_t read4bit(const uint8_t* data, uint16_t pixelIdx) {
  uint8_t b = pgm_read_byte(&data[pixelIdx >> 1]);
  return (pixelIdx & 1) ? (b & 0x0F) : (b >> 4);
}

// オーバーレイ連鎖: frameIdx から ref を辿り、ピクセルごとに最初に領域が
// 当たったオーバーレイのデータを使う。当たらなければ refDy だけシフトして
// 次の ref へ。フルフレームまで到達したらそこから読む。
static constexpr uint8_t MAX_OVL_CHAIN = 8;

static uint8_t buildOvlChain(uint8_t frameIdx, OvlDesc* chain, const uint8_t** fullOut) {
  uint8_t depth = 0;
  uint8_t f = frameIdx;
  while (pgm_read_byte(&frames[f].type) == 1 && depth < MAX_OVL_CHAIN) {
    chain[depth].data = (const uint8_t*)pgm_read_ptr(&frames[f].data);
    chain[depth].rx = pgm_read_byte(&frames[f].rx);
    chain[depth].ry = pgm_read_byte(&frames[f].ry);
    chain[depth].rw = pgm_read_byte(&frames[f].rw);
    chain[depth].rh = pgm_read_byte(&frames[f].rh);
    chain[depth].refDy = (int8_t)pgm_read_byte(&frames[f].refDy);
    depth++;
    f = pgm_read_byte(&frames[f].ref);
  }
  *fullOut = (const uint8_t*)pgm_read_ptr(&frames[f].data);
  return depth;
}

static uint8_t chainPixelIdx(const OvlDesc* chain, uint8_t depth, const uint8_t* full,
                             uint8_t srcX, int16_t srcY) {
  for (uint8_t d = 0; d < depth; d++) {
    const OvlDesc& o = chain[d];
    if (srcX >= o.rx && srcX < o.rx + o.rw && srcY >= o.ry && srcY < o.ry + o.rh) {
      return read4bit(o.data, (uint16_t)(srcY - o.ry) * o.rw + (srcX - o.rx));
    }
    srcY -= o.refDy;
    if (srcY < 0 || srcY >= IMG_H) return 0;  // シフトで画像外に出た行は背景
  }
  return read4bit(full, (uint16_t)srcY * IMG_W + srcX);
}
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

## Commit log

2026-01-11 Add battery saving feature with sleep mode and backlight control
2026-01-11 Enable PWM backlight dimming and fix dim-to-full transition
2026-01-17 Add SSD1351 OLED support with USE_SSD1351 macro switch
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2026-02-07 Invert accelerometer X/Y signs for SSD1331 layout change
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2026-03-01 Add iconcard KiCad schematic, PCB layout, and custom footprints
    [iconcard.kicad_pcb, iconcard.kicad_sch]
2026-03-01 Update tact switch to SKRPACE010, fix LCSC part numbers, add production files
    [IconCard_V0_bom.csv, IconCard_V0_designators.csv, IconCard_V0_positions.csv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]
2026-03-14 Move STAT LED from PA6 to PA8, update R2 to 4.7K
    [iconcard.kicad_sch]
2026-03-14 Add BL MOSFET driver, SWD test points, update J2 to 8-pin
    [iconcard.kicad_pcb, iconcard.kicad_sch]
2026-03-14 Add README, add Puchi-Pix branding to PCB silkscreen
    [iconcard.kicad_pcb]
2026-03-14 Support icons without entrance animation, fix palette white preservation
    [puchi_pix.ino]
2026-03-14 Flip accelerometer X/Y orientation for SSD1331 and SSD1351
    [puchi_pix.ino]
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2026-03-14 Add pixel art logo to PCB silkscreen
    [puchi_pix.kicad_pcb]
2026-03-15 Add files for JLCPCB
    [IconCard_V0_positions.csv, PuchiPix_V0_9_bom.csv, PuchiPix_V0_9_designators.csv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]
2026-03-21 Extract OLED brightness constants, increase for LiPo, and add fade start delay
2026-03-22 Fix orientation change: add cooldown with queue, raise thresholds, always fade
    [puchi_pix.ino]
2026-03-22 Refactor display code into per-device headers with clean abstraction layer
2026-03-23 Fix STAT LED polarity for active-low circuit
    [display_ssd1331.h, display_ssd1351.h]
2026-04-05 Switch ST7735 to RGB565 and remove redundant clearMargins
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2026-04-11 Move Puchi-Pix box 3D model files into box/ directory
    [box-l.stl, box-u.stl, box.3mf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]
2026-04-12 Add puchi_pix_esp32 KiCad project with LCSC part numbers
    [puchi_pix_esp32.kicad_pcb, puchi_pix_esp32.kicad_sch]
2026-04-12 Add ESP32-C3 test firmware with deep sleep and backlight hold
2026-04-12 Update D1 to green LED (C12624) with R3=4.7k and add production files
    [bom.csv, designators.csv, positions.csv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]
2026-04-22 Add icon_original sample and switch puchi_pix include to it
2026-05-05 Add ESP32 enclosure Blender source (box-esp32.blend)
    [box-esp32.blend]
2026-05-05 Ignore STL/3MF exports under box/ and untrack existing STL/3MF files
    [box-l.stl, box-u.stl, box.3mf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]
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2026-05-05 Add gc9a01_rotate_ble sketch and browser BLE upload tool with LittleFS persistence and text-labeled error splash
    [gc9a01_rotate_ble.ino]
2026-07-04 Finalize puchi_pix/esp32 layout and regenerate JLCPCB production files (puchi_pix V0_95)
    [PuchiPix_V0_95_bom.csv, PuchiPix_V0_95_designators.csv, PuchiPix_V0_95_positions.csv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]
2026-08-09 Fit box and box-esp32 enclosures to 300mAh battery
    [box-esp32.blend, box.blend]
2026-08-09 Track box STL exports (box u/l, box-esp32 a/b/c)
    [box-esp32-a.stl, box-esp32-b.stl, box-esp32-c.stl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]
2026-08-09 Add v3 diff-chain payload with keyframes and multi-rect patches, removing the fixed frame cap
    [gc9a01_rotate_ble.ino]
2026-08-09 Follow flipped board mount: mirror accel X and recalibrate neutral bin
    [gc9a01_rotate_ble.ino]
2026-08-09 Add overlay ref chaining and 1px ref shift for compact animations, moving walk frame roles into generated icon headers
2026-08-09 Rename gc9a01_rotate_ble to puchi_pix_esp32, remove legacy gc9a01 sketches, and add ESP32 CI job
2026-08-11 Add frame range selection to BLE uploader for oversized GIFs
2026-08-11 Update ESP32 box enclosure models
    [box-esp32-a.stl, box-esp32-b.stl, box-esp32-c.stl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]
2026-08-11 Batch SPI row writes in ESP32 renderer to reduce redraw flicker
2026-08-11 Replace tilt lowpass with dt-scaled 200ms filter to stop hand-held bin jitter
    [puchi_pix_esp32.ino]
2026-08-12 Document ESP32 BOOT+RST sequence and connect-failure recovery in README
2026-08-12 Replace motion frame inputs with drag-handle timeline and optional entry segment
    [puchi_pix_esp32.ino]
2026-08-12 Fix ESP32 recovery order: enter bootloader before reconnecting USB
2026-08-12 Light the status LED (GPIO0, active low) while a BLE central is connected
2026-08-12 Detect handling via orientation drift with fixed-point lowpass, repurposing the LED and adding macro-gated accel diagnostics
    [puchi_pix_esp32.ino]
2026-08-12 Drive display power from the presentation phases: full brightness while playing, dim on GAP, sleep 10s later
2026-08-12 Add drift-based handling detection, segmented animation roles, and phase-driven display power to STM32 firmware
    [puchi_pix.ino]
2026-08-12 Add CLAUDE.md pointing to project skills and update generate-icon-data skill to current generator spec
2026-08-14 Add uploader preset save/load/URL sharing and speed=0 no-walk motion mode, fix bg change resetting timeline markers
    [puchi_pix_esp32.ino]
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2026-08-14 Update case models and add support structure blend
    [box-esp32-a.stl, box-esp32-c.stl, box-esp32.blend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]
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2026-09-07 Fix design-review findings: I2C/PFET-gate pull-ups, red-column VDROP, D1/L1 part selection, USB-C 16P, USB power policy, MBI GCLK dead time and sleep leak paths
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2026-09-13 Route the LED matrix lattice (F.Cu columns, In2 rows), place and route the back side, swap J1 to an SMD-shell USB-C, drop J3/J4
2026-09-13 Unify vias to 0.45/0.2, move decoupling caps next to their pins, tidy LED silkscreen
2026-09-13 Add POWER netclass (0.3mm) and set signal tracks to 0.1mm; close the boost and MCU ground loops on B.Cu
2026-09-13 Bridge the +5V trunk along the top edge (0.59 -> 0.17 ohm to the first PFET)
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2026-09-14 Swap J2 to JST SH with v1 power pin order (1:GND 2:+3V3S); replace the battery symbol with four pogo-pin contacts (VBAT/GND)
2026-09-14 Fill LCSC part numbers for JLCPCB assembly; switch the column drivers to MBI5124GP-B (pin 21 GCLK -> /OE, net MBI_OE); R2 133k, in-stock LED/NOR listings
2026-09-14 Rewrite the matrix driver for MBI5124: 8-plane BCM over SPI2 with TIM1 one-pulse /OE, 8-bit frame buffer
2026-09-14 Review fixes: guard the first plane against ISR re-entry, SPI2 8 MHz for the 3.3V chain delay, release the KXTJ3 latched INT, force /OE high on stop; J2 real part name and footprint id; drop MBI5153 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
2026-09-14 Move SW1 into the +3V3S branch (boost VIN on VBAT) so the 0.1A switch carries only the MCU rail; R101 2.0k / red series 120R for the MBI5124 10mA limit and USB headroom; R9 4.7k; C1 next to U1; In1 G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
2026-09-14 Relink BT1/BT2 footprints to their schematic symbols and restore the battery route to SW1/C1; firmware checks VBUS before enabling the boost now that VIN stays on the battery
2026-09-14 Add C106 10uF bulk capacitor on +5V next to the row PFET column (row switching transient, USB headroom)
2026-09-14 First version ordered at JLCPCB: relink BT1-BT4 and sync LCSC fields to the board, Fabrication Toolkit settings and the production files as uploaded
2026-09-27 Vendor the ST USB Device Library core, composite builder, MSC and CDC into the card sketch: the core only wires CDC/HID, so the sketch builds its own composite device
2026-10-04 Card case Blender model (front frame, pixel grid, lid) checked in so scripted edits can be rolled back
2026-10-10 Card case: battery tray (three cells, terminal openings and tab holes) with four ears seated in receivers added to the front frame
2026-10-10 Card: blank the matrix after 30 s without motion on USB power too, sleeping only on battery
2026-10-10 Card: eight NOR payload slots stepped by a deliberate shake, uploader picks and clears slots; idle check signed so an ISR-fresh activity stamp cannot read as a timeout
2026-10-12 Card case: no-battery lid variant (ceiling lowered to 10.2 mm over the tongue) for USB-powered demo units whose boost converter burns out
